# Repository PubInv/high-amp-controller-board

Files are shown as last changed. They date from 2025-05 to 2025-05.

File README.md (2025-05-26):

# high-amp-controller-board
A PCB assembly for controlling up to 60 amps of power for electolysis of electroplating

# Control V1.2 aka 1V1
Orginaly derived from NASA COG 1.1

On line schematic viewing from **Kicanvas** See: https://kicanvas.org  
The Control V1 is an Arduino DUE "Shield". The DUE will live below this printed wiring assembly. An Ethernet shield will live above as a "Socket". See KiCad Symbol & Footprint Library for Arduino Modules for "Shield" and "Socket"

## Schematics
### Browser page view of the schematic by KiCanvas.org 
Top page is "Control v1.kicad_sch". Note the page for MAX31856 is actualy for an MCP9600 but the page was not renamed (as of 20230830)
*  [Control1v1.kicad_sch](https://kicanvas.org/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)
* [Adafruit-MAX31850-thermocouple-breakout-board.kicad_sch](https://kicanvas.org/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)
* [Adafruit-MAX31855-breakout-board.kicad_sch](https://kicanvas.org/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)
* [Adafruit-MAX31856-PCB-master.kicad_sch](https://kicanvas.org/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)
* [Fan controller.kicad_sch](https://kicanvas.org/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)
* [I2C_Level_Shifter.kicad_sch](https://kicanvas.org/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)
* [SPI_ControllerLevel_Shifter.kicad_sch](https://kicanvas.org/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)
* [SSR Interface.kicad_sch](https://kicanvas.org/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)
* [display_interface.kicad_sch](https://kicanvas.org/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)

## PCB / PWA
### Browser page view of the PCB by KiCanvas.org 
Printed Circuit Board, Printed Wiring Assembly
* [Control 1v1.kicad_pcb](https://kicanvas.org/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)

### PCB / PWA 3D Snapshot


### BOM and Parts List
File Notes:
See notes on the Gerbers, BOM and placement files at:
https://github.com/PubInv/NASA-COG/issues/342

## License, Public Invention for this PCB, PWA
* [Firmware: Affero GPL 3.0](https://www.gnu.org/licenses/agpl-3.0.en.html#license-text)
* [CERN Open Hardware Licence Version 2 - Strongly Reciprocal](https://ohwr.org/cern_ohl_s_v2.txt)

<hr> 

## KiCad Symbol & Footprint Library for Arduino Modules
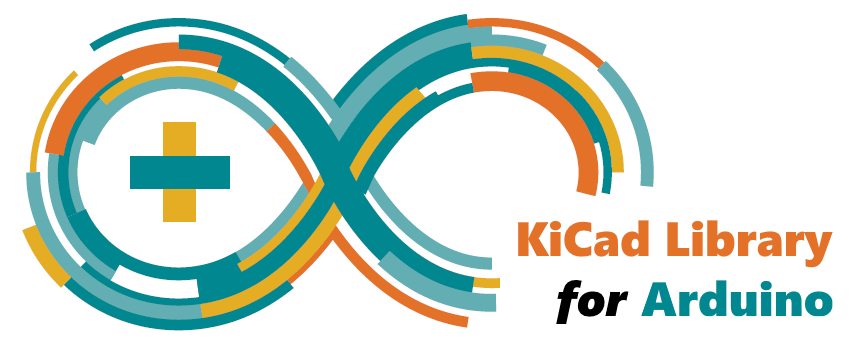
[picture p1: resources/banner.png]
<a href="./PICS/Rev2/PWA_FrontView.png">  
*Version 4.1.0*  

     

This is a library of KiCad schematic symbols and PCB footprints for most Arduino modules. You can use them to make your own PCB design which will effortlessly connect with your chosen Arduino module.

Currently included modules:
- Arduino **101** Shield
- Arduino **Due** Shield
- Arduino **Giga R1 WiFi** Shield
- Arduino **Leonardo** Shield
- Arduino **M0** Shield
- Arduino **M0 Pro** Shield
- Arduino **Mega 2560 R3** Shield
- Arduino **Micro** Socket
- Arduino **Mini** Socket
- Arduino **MKR 1000 WiFi** Socket
- Arduino **MKR WiFi 1010** Socket
- Arduino **MKR FOX 1200** Socket
- Arduino **MKR WAN 1300** Socket
- Arduino **MKR WAN 1310** Socket
- Arduino **MKR GSM 1400** Socket
- Arduino **MKR NB 1500** Socket
- Arduino **MKR Vidor 4000** Socket
- Arduino **MKR Zero** Socket
- Arduino **Nano** Socket
- Arduino **Nano 33 BLE** Socket / Tile
- Arduino **Nano 33 BLE Sense** Socket / Tile
- Arduino **Nano 33 BLE Sense R2** Socket / Tile
- Arduino **Nano 33 IoT** Socket / Tile
- Arduino **Nano Every** Socket / Tile
- Arduino **Nano RP2040 Connect** Socket / Tile
- Arduino **Nicla Sense ME** Socket / Tile
- Arduino **Nicla Vision** Socket / Tile
- Arduino **Nicla Voice** Socket / Tile
- Arduino **Pro Mini** Socket
- Arduino **Uno R1** Shield
- Arduino **Uno R2** Shield
- Arduino **Uno R3** Shield
- Arduino **Uno R3 SMD** Shield
- Arduino **Uno R4 Minima** Shield
- Arduino **Uno R4 WiFi** Shield
- Arduino **Uno WiFi R2** Shield
- Arduino **Zero** Shield
- Clone **Mega 2560 Pro** Socket
- Clone **Pro Mini** Socket

*"Shield" means the module is designed to plug in from beneath your PCB. "Socket" means the module is designed to plug in from above your PCB. "Tile" means the module is designed to be soldered directly on to your PCB using surface-mount pads.*

## KiCad Version Compatibility
This library requires at least KiCad 6 to function, and is tested on KiCad versions 6.0.8 and 7.0.2. Note that the installation procedure is different for KiCad 6 and 7; please see the [Library Installation](#library-installation) section below.

## Comments, Requests, Bugs & Contributions
All are welcome!
Please open an [Issue](https://github.com/Alarm-Siren/arduino-kicad-library/issues) or [Pull Request](https://github.com/Alarm-Siren/arduino-kicad-library/pulls), as appropriate.

## Library Installation
To install this library in your copy of KiCad, choose the correct section for your version of KiCad and follow the steps given. These instructions only cover automated installation using KiCad's built-in Package and Content Manager (PCM); manual installation is possible but not supported.

### KiCad 7

**Warning**: Do not change the nickname prefix from that given in step 4 below. If you do so KiCad will not assign the correct footprints to the symbols by default.

1. Open KiCad and open the Preferences window at "Preferences" -> "Preferences..."
2. Select the "Plugin and Content Manager" section in the left-hand pane.
3. Ensure that the "Automatically add installed libraries to the global lib table" option is ticked.
4. Ensure that the "Library nickname prefix" is set to "PCM_".
5. Ensuring that the "Check for package updates on startup" option is ticked is recommended. **(Optional)**
6. Click "OK" to close the Preferences window.
7. Click the "Plugin and Content Manager" button.
8. Select the "KiCad official repository" from the top drop-down box (if not already selected).
9. Go the Libraries tab and locate the "KiCad Library for Arduino Modules" in the list.
10. Click the "Install" button for that entry in the list.
11. Click "Apply Pending Changes".
12. Close the "Applying Package Changes" window once it has finished.
13. You should now find that this library is listed in the "Installed" tab.
14. Close the Plugin and Content Manager.
15. You may need to restart KiCad for the library installation to fully take effect. **(Optional)**
16. All done: you are now ready to use these schematic components and footprints in your projects!

### KiCad 6
**Recommendation:** If you can, you should upgrade to KiCad 7.

**Warning**: Do not change the Nicknames from those given in steps 12 and 18 below. If you do so KiCad will not assign the correct footprints to the symbols by default.

1. Open KiCad and click the "Plugin and Content Manager" button.
2. Select the "KiCad official repository" from the top drop-down box (if not already selected).
3. Go the Libraries tab and locate the "KiCad Library for Arduino Modules" in the list.
4. Click the "Install" button for that entry in the list.
5. Click "Apply Changes".
6. Close the "Applying Package Changes" window once it has finished.
7. You should now find that this library is listed in the "Installed" tab.
8. Close the Plugin and Content Manager.
9. Go to the "Preferences" -> "Manage Symbol Libraries..." menu option.
10. In the Symbol Libraries dialogue that appears, switch to the "Global Libraries" tab (if not already selected).
11. Click "Add empty row to table" button (the button with a big cross in it, beneath the table).
12. In the new line of the table, set the Nickname to "PCM_arduino-library", and ensure the Library Format is set to "KiCad".
13. In the same line of the table, set Library Path to "${KICAD6_3RD_PARTY}/symbols/com_github_alarm-siren_arduino-kicad-library/arduino-library.kicad_sym".
14. Click "OK" to close the Symbol Libraries dialogue.
15. Go to "Preferences" -> "Manage Footprint Libraries..." menu option.
16. In the Footprint Libraries dialogue that appears, switch to the "Global Libraries" tab (if not already selected).
17. Click "Add empty row to table" button (the button with a big cross in it, beneath the table).
18. In the new line of the table, set the Nickname to "PCM_arduino-library", and ensure the Library Format is set to "KiCad".
19. In the same line of the table, set Library Path to "${KICAD6_3RD_PARTY}/footprints/com_github_alarm-siren_arduino-kicad-library/arduino-library.pretty".
20. Click "OK" to close the Footprint Libraries dialogue.
21. All done: you are now ready to use these schematic components and footprints in your projects!

## Donations

I really hope you've found this library useful. If you'd like to buy me a beer in thanks for the work I put into it, you can make a donation using the button below:



## License & Legal
Copyright 2017-2023, [Nicholas Parks Young](https://github.com/Alarm-Siren).

Except as otherwise noted, all content of this library is licensed under the 
[Creative Commons Attribution-ShareAlike 4.0 International License](https://creativecommons.org/licenses/by-sa/4.0/), with the following additional exception:
> To the extent that the creation of electronic designs that use the Licensed Material can be considered to be Adapted Material, the Licensor waives Section 3 of the Public License with respect to these electronic designs and any generated files which incorporate data provided as part of the Licensed Material.



### "KiCad Library for Arduino" Banner & Icon

The two images "resources/banner.png" and "resources/icon.png" are licensed under the [Creative Commons Attribution-NonCommercial-ShareAlike 4.0 International License](https://creativecommons.org/licenses/by-nc-sa/4.0/). These images are derivatives of ["Arduino Open-Source Community: Main Logotype RGB Colors" originally created by Arduino](https://www.arduino.cc/en/trademark/community-logo). 

Original Images: Copyright 2013, [Arduino](https://www.arduino.cc/). Derived Images: Copyright 2023, [Nicholas Parks Young](https://github.com/Alarm-Siren).



### Arduino Trademark

The word "Arduino" is a registered trademark of [Arduino](https://www.arduino.cc/). This trademark is used in this library to refer to Arduino products and to identify Arduino-related non-commercial content, as permitted by Arduino's [trademark guidelines](https://www.arduino.cc/en/trademark). This project is not affiliated with nor endorsed by Arduino.

## FAQ

Answers to some common questions about this library.

### Is this library in active development?

Yes. For the foreseeable future, I will be providing support, bug-fixes and updating the library with any new Arduino modules as they are released.

### What does the license exception in the License & Legal section mean?

This library uses the same license as KiCad's own built-in parts library does, including the exception. The KiCad Libraries team have a [page which explains the meaning of the exception](https://www.kicad.org/libraries/license/). My version of the exception uses slightly better wording, but the effect is the same.

### Why do the footprints not have an `Edge.Cuts` outline?

If I put in an `Edge.Cuts` outline, then those users who want to have a PCB larger than the module footprint would have to modify the footprint to do so. In my experience, it is far more common for users to want a PCB larger than the module anyway, so I prefer to cater to those users. If you want your PCB to be the same size and shape as the Arduino module, you can trace the `F.Silkscreen` or `B.Silkscreen` layer (as appropriate) out in the `Edge.Cuts` layer yourself, or you can modify the footprint to change the outline from `F.Silkscreen` or `B.Silkscreen` layer to `Edge.Cuts`.

### Why do the Nicla Vision and Nicla Voice tile footprints have cut-outs?

The cut-outs are necessary to accommodate components on the back of those modules; without them the components would physically prevent you from getting the module's pads down to the footprint's SMD pads.

### Why does the whole footprint have an `F.Courtyard` or `B.Courtyard` outline? I can't place my components where I need to!

Firstly, this does not stop you from placing your components wherever you want. It does mean that the KiCad DRC will, by default, report errors or warnings in some circumstances because the module footprint and your circuit's footprints' courtyards are overlapping, but you can ignore or disable these errors/warnings without issue.

Secondly, the intention is that it acts as a warning to the user that they've put components in the 'danger zone' between their PCB and the Module. I do not model all of the tall components on the module, so it is possible that a user might unknowingly place their own tall component in a position that would conflict with one on the module. My hope is that the DRC errors/warnings will flag this potential problem to the user to manually check that their placement does not conflict with the module.

In principle I'm open to marking the taller components specifically, which would remove this issue, but this is a lot of work and requires data I don't have access to for all the modules.

### Why is this Power Pin set to Power Input/Power Output/Unconnected? I get DRC errors because of it!

The short answer is that some power pins on some modules can be used as either inputs or outputs, depending on your circuit design / where you're powering the assembly from.

For those pins where I've been able to categorically confirm that the given power pin is Unconnected by default, or must necessarily be a Power Input or a Power Output, I have set it as such. For those pins that can be used as either an input or output, I have set it to Power Input as this is the more flexible option whilst still preserving some element of DRC capability. If you're using one of these Power Input pins as a Power Output from the module, you'll need to add the special "PWR_FLAG" component to the affected net to make the DRC error go away.

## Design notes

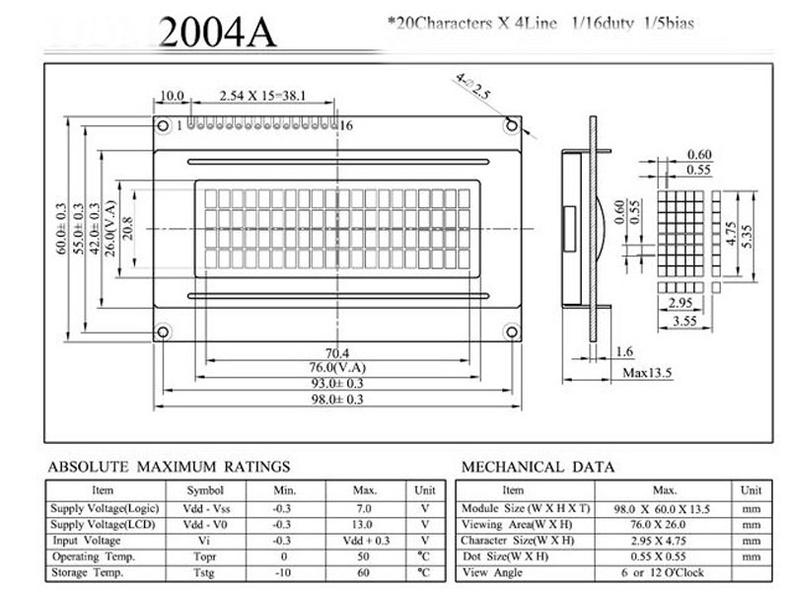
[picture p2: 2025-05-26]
PublicInvention_KiCad_Library/Parts/20x4DisplayMechanical.jpg

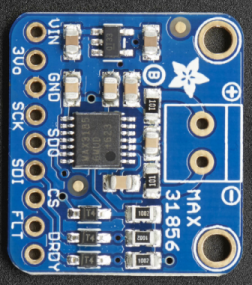
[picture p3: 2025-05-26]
resources/Adafruit_MAX31856.png

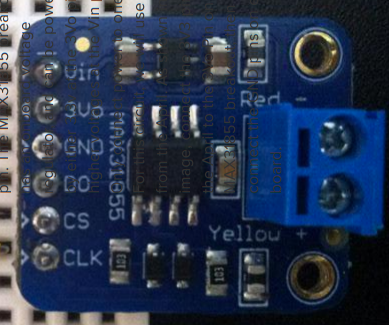
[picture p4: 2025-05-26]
resources/Adafruit_MAX31855.png

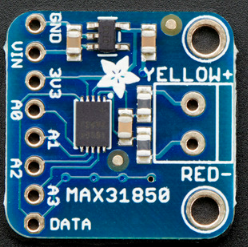
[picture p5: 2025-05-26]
resources/Adafruit_MAX31850.png

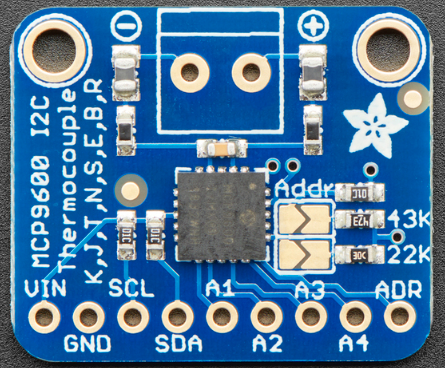
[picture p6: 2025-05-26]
resources/Adafruit_MCP9600.png

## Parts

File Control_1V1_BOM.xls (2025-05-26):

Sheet: RAW
Source: | C:\Users\Public\Downloads\Arduino\PubInv\NASA-COG\elec\Control Board\Control_1v1\Control_1v1\Control_1v1.kicad_sch
Date: | 10/11/2023 9:02:01 PM
Tool: | Eeschema 7.0.5
Generator: | C:\Program Files\KiCad\6.0\bin\scripting\plugins/bom_csv_grouped_by_value.py
Component Count: | 287
Individual Components:
Item | Qty | Reference(s) | Value | LibPart | Footprint | Datasheet | Assembly Type | AssemblyType | Category | Cost | DK_Datasheet_Link | DK_Detail_Page | Description | Digi-Key_PN | Distributor 1 | Distributor 1 PN | Distributor 2 | Distributor 2 PN | Family | LongLead | MPN | Manufacturer | Part Number | Status
 |  | A1 | Arduino_Due_Shield | arduino-library:Arduino_Due_Shield | PubInv_KiCad_PCB:Arduino_Due_Shield_Annotated | https://docs.arduino.cc/hardware/due
 |  | C1 | 39pF | Device:C | Capacitor_SMD:C_0603_1608Metric_Pad1.08x0.95mm_HandSolder | https://datasheet.lcsc.com/lcsc/1811082118_YAGEO-CC0603JRNPO9BN390_C107049.pdf |  | SMT |  | 0.003 |  |  | 50V 39pF NP0 Â±5% 0603 Multilayer Ceramic Ca |  | JLCPCB | C107049 |  |  |  | NO | CC0603JRNPO9BN390 | YAGEO
 |  | C2 | 39pF | Device:C | Capacitor_SMD:C_0603_1608Metric_Pad1.08x0.95mm_HandSolder | https://datasheet.lcsc.com/lcsc/1811082118_YAGEO-CC0603JRNPO9BN390_C107049.pdf |  | SMT |  | 0.003 |  |  | 50V 39pF NP0 Â±5% 0603 Multilayer Ceramic Ca |  | JLCPCB | C107049 |  |  |  | NO | CC0603JRNPO9BN390 | YAGEO
 |  | C3 | 39pF | Device:C | Capacitor_SMD:C_0603_1608Metric_Pad1.08x0.95mm_HandSolder | https://datasheet.lcsc.com/lcsc/1811082118_YAGEO-CC0603JRNPO9BN390_C107049.pdf |  | SMT |  | 0.003 |  |  | 50V 39pF NP0 Â±5% 0603 Multilayer Ceramic Ca |  | JLCPCB | C107049 |  |  |  | NO | CC0603JRNPO9BN390 | YAGEO
 |  | C4 | 39pF | Device:C | Capacitor_SMD:C_0603_1608Metric_Pad1.08x0.95mm_HandSolder | https://datasheet.lcsc.com/lcsc/1811082118_YAGEO-CC0603JRNPO9BN390_C107049.pdf |  | SMT |  | 0.003 |  |  | 50V 39pF NP0 Â±5% 0603 Multilayer Ceramic Ca |  | JLCPCB | C107049 |  |  |  | NO | CC0603JRNPO9BN390 | YAGEO
 |  | C5 | 39pF | Device:C | Capacitor_SMD:C_0603_1608Metric_Pad1.08x0.95mm_HandSolder | https://datasheet.lcsc.com/lcsc/1811082118_YAGEO-CC0603JRNPO9BN390_C107049.pdf |  | SMT |  | 0.003 |  |  | 50V 39pF NP0 Â±5% 0603 Multilayer Ceramic Ca |  | JLCPCB | C107049 |  |  |  | NO | CC0603JRNPO9BN390 | YAGEO
 |  | C6 | 39pF | Device:C | Capacitor_SMD:C_0603_1608Metric_Pad1.08x0.95mm_HandSolder | https://datasheet.lcsc.com/lcsc/1811082118_YAGEO-CC0603JRNPO9BN390_C107049.pdf |  | SMT |  | 0.003 |  |  | 50V 39pF NP0 Â±5% 0603 Multilayer Ceramic Ca |  | JLCPCB | C107049 |  |  |  | NO | CC0603JRNPO9BN390 | YAGEO
 |  | C7 | 39pF | Device:C | Capacitor_SMD:C_0603_1608Metric_Pad1.08x0.95mm_HandSolder | https://datasheet.lcsc.com/lcsc/1811082118_YAGEO-CC0603JRNPO9BN390_C107049.pdf |  | SMT |  | 0.003 |  |  | 50V 39pF NP0 Â±5% 0603 Multilayer Ceramic Ca |  | JLCPCB | C107049 |  |  |  | NO | CC0603JRNPO9BN390 | YAGEO
 |  | C8 | 39pF | Device:C | Capacitor_SMD:C_0603_1608Metric_Pad1.08x0.95mm_HandSolder | https://datasheet.lcsc.com/lcsc/1811082118_YAGEO-CC0603JRNPO9BN390_C107049.pdf |  | SMT |  | 0.003 |  |  | 50V 39pF NP0 Â±5% 0603 Multilayer Ceramic Ca |  | JLCPCB | C107049 |  |  |  | NO | CC0603JRNPO9BN390 | YAGEO
 |  | C9 | 39pF | Device:C | Capacitor_SMD:C_0603_1608Metric_Pad1.08x0.95mm_HandSolder | https://datasheet.lcsc.com/lcsc/1811082118_YAGEO-CC0603JRNPO9BN390_C107049.pdf |  | SMT |  | 0.003 |  |  | 50V 39pF NP0 Â±5% 0603 Multilayer Ceramic Ca |  | JLCPCB | C107049 |  |  |  | NO | CC0603JRNPO9BN390 | YAGEO
 |  | C10 | 39pF | Device:C | Capacitor_SMD:C_0603_1608Metric_Pad1.08x0.95mm_HandSolder | https://datasheet.lcsc.com/lcsc/1811082118_YAGEO-CC0603JRNPO9BN390_C107049.pdf |  | SMT |  | 0.003 |  |  | 50V 39pF NP0 Â±5% 0603 Multilayer Ceramic Ca |  | JLCPCB | C107049 |  |  |  | NO | CC0603JRNPO9BN390 | YAGEO
 |  | C11 | 39pF | Device:C | Capacitor_SMD:C_0603_1608Metric_Pad1.08x0.95mm_HandSolder | https://datasheet.lcsc.com/lcsc/1811082118_YAGEO-CC0603JRNPO9BN390_C107049.pdf |  | SMT |  | 0.003 |  |  | 50V 39pF NP0 Â±5% 0603 Multilayer Ceramic Ca |  | JLCPCB | C107049 |  |  |  | NO | CC0603JRNPO9BN390 | YAGEO
 |  | C12 | 39pF | Device:C | Capacitor_SMD:C_0603_1608Metric_Pad1.08x0.95mm_HandSolder | https://datasheet.lcsc.com/lcsc/1811082118_YAGEO-CC0603JRNPO9BN390_C107049.pdf |  | SMT |  | 0.003 |  |  | 50V 39pF NP0 Â±5% 0603 Multilayer Ceramic Ca |  | JLCPCB | C107049 |  |  |  | NO | CC0603JRNPO9BN390 | YAGEO
 |  | C13 | 39pF | Device:C | Capacitor_SMD:C_0603_1608Metric_Pad1.08x0.95mm_HandSolder | https://datasheet.lcsc.com/lcsc/1811082118_YAGEO-CC0603JRNPO9BN390_C107049.pdf |  | SMT |  | 0.003 |  |  | 50V 39pF NP0 Â±5% 0603 Multilayer Ceramic Ca |  | JLCPCB | C107049 |  |  |  | NO | CC0603JRNPO9BN390 | YAGEO
 |  | C14 | 39pF | Device:C | Capacitor_SMD:C_0603_1608Metric_Pad1.08x0.95mm_HandSolder | https://datasheet.lcsc.com/lcsc/1811082118_YAGEO-CC0603JRNPO9BN390_C107049.pdf |  | SMT |  | 0.003 |  |  | 50V 39pF NP0 Â±5% 0603 Multilayer Ceramic Ca |  | JLCPCB | C107049 |  |  |  | NO | CC0603JRNPO9BN390 | YAGEO
 |  | C15 | 39pF | Device:C | Capacitor_SMD:C_0603_1608Metric_Pad1.08x0.95mm_HandSolder | https://datasheet.lcsc.com/lcsc/1811082118_YAGEO-CC0603JRNPO9BN390_C107049.pdf |  | SMT |  | 0.003 |  |  | 50V 39pF NP0 Â±5% 0603 Multilayer Ceramic Ca |  | JLCPCB | C107049 |  |  |  | NO | CC0603JRNPO9BN390 | YAGEO
 |  | C16 | 1uF | Device:C | Capacitor_SMD:C_0603_1608Metric_Pad1.08x0.95mm_HandSolder | CC0603JRX7R9BB104.pdf |  | SMT |  | 0.0037 |  |  | 50V 1uF Â±5% 0603 Multilayer Ceramic Ca |  | JLCPCB | C91183 |  |  |  | NO | CC0603JRX7R9BB104 | YAGEO
 |  | C17 | 1uF | Device:C | Capacitor_SMD:C_0603_1608Metric_Pad1.08x0.95mm_HandSolder | CC0603JRX7R9BB104.pdf |  | SMT |  | 0.0037 |  |  | 50V 1uF Â±5% 0603 Multilayer Ceramic Ca |  | JLCPCB | C91183 |  |  |  | NO | CC0603JRX7R9BB104 | YAGEO
 |  | C18 | 1uF | Device:C | Capacitor_SMD:C_0603_1608Metric_Pad1.08x0.95mm_HandSolder | CC0603JRX7R9BB104.pdf |  | SMT |  | 0.0037 |  |  | 50V 1uF Â±5% 0603 Multilayer Ceramic Ca |  | JLCPCB | C91183 |  |  |  | NO | CC0603JRX7R9BB104 | YAGEO
 |  | C19 | 1uF | Device:C | Capacitor_SMD:C_0603_1608Metric_Pad1.08x0.95mm_HandSolder | CC0603JRX7R9BB104.pdf |  | SMT |  | 0.0037 |  |  | 50V 1uF Â±5% 0603 Multilayer Ceramic Ca |  | JLCPCB | C91183 |  |  |  | NO | CC0603JRX7R9BB104 | YAGEO
 |  | C20 | 39pF | Device:C | Capacitor_SMD:C_0603_1608Metric_Pad1.08x0.95mm_HandSolder | https://datasheet.lcsc.com/lcsc/1811082118_YAGEO-CC0603JRNPO9BN390_C107049.pdf |  | SMT |  | 0.003 |  |  | 50V 39pF NP0 Â±5% 0603 Multilayer Ceramic Ca |  | JLCPCB | C107049 |  |  |  | NO | CC0603JRNPO9BN390 | YAGEO
 |  | C21 | 39pF | Device:C | Capacitor_SMD:C_0603_1608Metric_Pad1.08x0.95mm_HandSolder | https://datasheet.lcsc.com/lcsc/1811082118_YAGEO-CC0603JRNPO9BN390_C107049.pdf |  | SMT |  | 0.003 |  |  | 50V 39pF NP0 Â±5% 0603 Multilayer Ceramic Ca |  | JLCPCB | C107049 |  |  |  | NO | CC0603JRNPO9BN390 | YAGEO
 |  | C22 | 10nF | Device:C | Capacitor_SMD:C_0603_1608Metric_Pad1.08x0.95mm_HandSolder | ~ |  | SMT |  | 0.0132 |  |  |  |  | JLCPCB | C389113 |  |  |  |  | CC0603JRNPO9BN103 | YAGEO
 |  | C23 | 39pF | Device:C | Capacitor_SMD:C_0603_1608Metric_Pad1.08x0.95mm_HandSolder | https://datasheet.lcsc.com/lcsc/1811082118_YAGEO-CC0603JRNPO9BN390_C107049.pdf |  | SMT |  | 0.003 |  |  | 50V 39pF NP0 Â±5% 0603 Multilayer Ceramic Ca |  | JLCPCB | C107049 |  |  |  | NO | CC0603JRNPO9BN390 | YAGEO
 |  | CIPO1 | CIPO | Connector:TestPoint | TestPoint:TestPoint_Loop_D2.54mm_Drill1.5mm_Beaded | ~ |  | HAND |  | 0
 |  | COPI1 | COPI | Connector:TestPoint | TestPoint:TestPoint_Loop_D2.54mm_Drill1.5mm_Beaded | ~ |  | HAND |  | 0
 |  | D1 | 5.1V | Diode:BZV55B3V3 | Diode_SMD:D_MiniMELF | https://assets.nexperia.com/documents/data-sheet/BZV55_SER.pdf BZV55B3V3 |  | SMT |  | 0.0433 |  |  | Â±5% Single 1W 5.1V MELF Zener Diodes ROHS |  | JLCPCB | C841097 |  |  |  |  | DL4733A | LGE
 |  | D2 | 5.1V | Diode:BZV55B3V3 | Diode_SMD:D_MiniMELF | https://assets.nexperia.com/documents/data-sheet/BZV55_SER.pdf BZV55B3V3 |  | SMT |  | 0.0433 |  |  | Â±5% Single 1W 5.1V MELF Zener Diodes ROHS |  | JLCPCB | C841097 |  |  |  |  | DL4733A | LGE
 |  | D3 | 1N5819WS | Diode:1N5819WS | Diode_SMD:D_SOD-323 | https://datasheet.lcsc.com/lcsc/2204281430_Guangdong-Hottech-1N5819WS_C191023.pdf |  | SMT |  | 0.0119 |  |  | 40V 600mV@1A 1A SOD-323 Schottky Barrier Diodes (SBD) ROHS |  | JLCPCB | C191023 |  |  |  |  | 1N5819WS | Guangdong Hottech
 |  | D4 | RED 0603 | Device:LED | LED_SMD:LED_0603_1608Metric_Pad1.05x0.95mm_HandSolder | ~ |  | HAND | Optoelectronics | 0.0054 | http://optoelectronics.liteon.com/upload/download/DS22-2000-109/LTST-C171KRKT.pdf | /product-detail/en/lite-on-inc/LTST-C171KRKT/160-1427-1-ND/386800 | LED RED CLEAR SMD | 160-1427-1-ND | JLCPCB | C2286 |  |  | LED Indication - Discrete |  | LTST-C171KRKT | Lite-On Inc. |  | Active
 |  | D_PSU_RX1 | D_PSU_RX | Connector:TestPoint | TestPoint:TestPoint_Loop_D2.54mm_Drill1.5mm_Beaded | ~ |  | HAND |  | 0
 |  | D_PSU_RX2 | D_PSU_RX2 | Connector:TestPoint | TestPoint:TestPoint_Loop_D2.54mm_Drill1.5mm_Beaded | ~ |  | HAND |  | 0
 |  | D_PSU_TX1 | D_PSU_TX | Connector:TestPoint | TestPoint:TestPoint_Loop_D2.54mm_Drill1.5mm_Beaded | ~ |  | HAND |  | 0
 |  | D_PSU_TX2 | D_PSU_TX2 | Connector:TestPoint | TestPoint:TestPoint_Loop_D2.54mm_Drill1.5mm_Beaded | ~ |  | HAND |  | 0
 |  | H1 | MountingHole_Pad_3.5mm | GPAD_SCH_LIB:MountingHole_Pad_3.5mm | PubInv_KiCad_PCB:MountingHole_3.5mm_Pad_Via | ~ |  | NA |  | 0 |  |  | MountingHole_Pad_3.5mm |  | NA | NA
 |  | H2 | MountingHole_Pad_3.5mm | GPAD_SCH_LIB:MountingHole_Pad_3.5mm | PubInv_KiCad_PCB:MountingHole_3.5mm_Pad_Via | ~ |  | NA |  | 0 |  |  | MountingHole_Pad_3.5mm |  | NA | NA
 |  | H3 | MountingHole_Pad_3.5mm | GPAD_SCH_LIB:MountingHole_Pad_3.5mm | PubInv_KiCad_PCB:MountingHole_3.5mm_Pad_Via | ~ |  | NA |  | 0 |  |  | MountingHole_Pad_3.5mm |  | NA | NA
 |  | H4 | MountingHole_Pad_3.5mm | GPAD_SCH_LIB:MountingHole_Pad_3.5mm | PubInv_KiCad_PCB:MountingHole_3.5mm_Pad_Via | ~ |  | NA |  | 0 |  |  | MountingHole_Pad_3.5mm |  | NA | NA
 |  | H5 | MountingHole_Pad_3.5mm | GPAD_SCH_LIB:MountingHole_Pad_3.5mm | PubInv_KiCad_PCB:MountingHole_3.5mm_Pad_Via | ~ |  | NA |  | 0 |  |  | MountingHole_Pad_3.5mm |  | NA | NA
 |  | ISO1 | MountingHole_Pad_3.5mm | GPAD_SCH_LIB:MountingHole_Pad_3.5mm | PubInv_KiCad_PCB:MountingHole_3.5mm_Pad_Via | ~ |  | NA |  | 0 |  |  | MountingHole_Pad_3.5mm |  | NA | NA
 |  | ISO2 | MountingHole_Pad_3.5mm | GPAD_SCH_LIB:MountingHole_Pad_3.5mm | PubInv_KiCad_PCB:MountingHole_3.5mm_Pad_Via | ~ |  | NA |  | 0 |  |  | MountingHole_Pad_3.5mm |  | NA | NA
 |  | ISO3 | MountingHole_Pad_3.5mm | GPAD_SCH_LIB:MountingHole_Pad_3.5mm | PubInv_KiCad_PCB:MountingHole_3.5mm_Pad_Via | ~ |  | NA |  | 0 |  |  | MountingHole_Pad_3.5mm |  | NA | NA
 |  | ISO4 | MountingHole_Pad_3.5mm | GPAD_SCH_LIB:MountingHole_Pad_3.5mm | PubInv_KiCad_PCB:MountingHole_3.5mm_Pad_Via | ~ |  | NA |  | 0 |  |  | MountingHole_Pad_3.5mm |  | NA | NA
 |  | ISO5 | MountingHole_Pad_3.5mm | GPAD_SCH_LIB:MountingHole_Pad_3.5mm | PubInv_KiCad_PCB:MountingHole_3.5mm_Pad_Via | ~ |  | NA |  | 0 |  |  | MountingHole_Pad_3.5mm |  | NA | NA
 |  | J1 | DB9_Female_MountingHoles | Connector:DB9_Female_MountingHoles | Connector_Dsub:DSUB-9_Female_Horizontal_P2.77x2.84mm_EdgePinOffset4.94mm_Housed_MountingHolesOffset7.48mm | C141882_D-DMR009PF-D002.pdf |  | HAND |  | 0.2718 |  |  | 9P Female D-Sub Shrouded 2 3A -50â„ƒ~+105â„ƒ Plugin D-Sub/DVI/HDMI Connectors ROHS |  | JLCPCB | C141882 |  |  |  |  | D-DMR009PF-D002 | Ckmtw(Shenzhen Cankemeng)
 |  | J2 | Conn_01x08 | Connector_Generic:Conn_01x08 | Connector_PinSocket_2.54mm:PinSocket_1x08_P2.54mm_Vertical | https://jlcpcb.com/partdetail/Hctl-PZ254_1_08_Z_85/C2894931 |  | HAND |  | 0.0762 |  |  | 3A Straight Square Pins 2.5mm 8P 6mm -40â„ƒ~+105â„ƒ 3mm 2.54mm Plugin Black 1x8P Plugin,P=2.54mm Pin Headers ROHS |  | JLCPCB | C2894931 |  |  |  |  | PZ254-1-08-Z-8.5 | HCTL
 |  | J3 | Conn_01x08 | Connector_Generic:Conn_01x08 | Connector_PinSocket_2.54mm:PinSocket_1x08_P2.54mm_Vertical | https://jlcpcb.com/partdetail/Hctl-PZ254_1_08_Z_85/C2894931 |  | HAND |  | 0.0762 |  |  | 3A Straight Square Pins 2.5mm 8P 6mm -40â„ƒ~+105â„ƒ 3mm 2.54mm Plugin Black 1x8P Plugin,P=2.54mm Pin Headers ROHS |  | JLCPCB | C2894931 |  |  |  |  | PZ254-1-08-Z-8.5 | HCTL
 |  | J4 | Conn_01x08 | Connector_Generic:Conn_01x08 | Connector_PinSocket_2.54mm:PinSocket_1x08_P2.54mm_Vertical | https://jlcpcb.com/partdetail/Hctl-PZ254_1_08_Z_85/C2894931 |  | HAND |  | 0.0762 |  |  | 3A Straight Square Pins 2.5mm 8P 6mm -40â„ƒ~+105â„ƒ 3mm 2.54mm Plugin Black 1x8P Plugin,P=2.54mm Pin Headers ROHS |  | JLCPCB | C2894931 |  |  |  |  | PZ254-1-08-Z-8.5 | HCTL
 |  | J5 | Conn_01x08 | Connector_Generic:Conn_01x08 | Connector_PinSocket_2.54mm:PinSocket_1x08_P2.54mm_Vertical | https://jlcpcb.com/partdetail/Hctl-PZ254_1_08_Z_85/C2894931 |  | HAND |  | 0.0762 |  |  | 3A Straight Square Pins 2.5mm 8P 6mm -40â„ƒ~+105â„ƒ 3mm 2.54mm Plugin Black 1x8P Plugin,P=2.54mm Pin Headers ROHS |  | JLCPCB | C2894931 |  |  |  |  | PZ254-1-08-Z-8.5 | HCTL
 |  | J6 | Conn_01x08 | Connector_Generic:Conn_01x08 | Connector_PinSocket_2.54mm:PinSocket_1x08_P2.54mm_Vertical | https://jlcpcb.com/partdetail/Hctl-PZ254_1_08_Z_85/C2894931 |  | HAND |  | 0.0762 |  |  | 3A Straight Square Pins 2.5mm 8P 6mm -40â„ƒ~+105â„ƒ 3mm 2.54mm Plugin Black 1x8P Plugin,P=2.54mm Pin Headers ROHS |  | JLCPCB | C2894931 |  |  |  |  | PZ254-1-08-Z-8.5 | HCTL
 |  | J7 | Conn_01x10 | Connector_Generic:Conn_01x10 | Connector_PinSocket_2.54mm:PinSocket_1x10_P2.54mm_Vertical | https://jlcpcb.com/partdetail/Hctl-PZ254_1_10_Z_85/C2894933 |  | HAND |  | 0.0942 |  |  | 3A Straight Square Pins 2.5mm 10P 6mm -40â„ƒ~+105â„ƒ 3mm 2.54mm Plugin Black 1x10P Plugin,P=2.54mm Pin Headers ROHS |  | JLCPCB | C2894933 |  |  |  |  | PZ254-1-10-Z-8.5 | HCTL
 |  | J8 | Conn_02x18_Odd_Even | Connector_Generic:Conn_02x18_Odd_Even | Connector_PinSocket_2.54mm:PinSocket_2x18_P2.54mm_Vertical | C132131_DS1023-2_18SF11.pdf |  | HAND |  | 0.3441 |  |  | 2.54mm 2.54mm åŒæŽ’ 36P Straight 2x18P Plugin,P=2.54mm Female Headers ROHS |  | JLCPCB | C132131
 |  | J9 | Conn_01x10 | Connector_Generic:Conn_01x10 | Connector_PinSocket_2.54mm:PinSocket_1x10_P2.54mm_Vertical | https://jlcpcb.com/partdetail/Hctl-PZ254_1_10_Z_85/C2894933 |  | HAND |  | 0.0942 |  |  | 3A Straight Square Pins 2.5mm 10P 6mm -40â„ƒ~+105â„ƒ 3mm 2.54mm Plugin Black 1x10P Plugin,P=2.54mm Pin Headers ROHS |  | JLCPCB | C2894933 |  |  |  |  | PZ254-1-10-Z-8.5 | HCTL
 |  | J10 | Conn_02x12_Odd_Even | Connector_Generic:Conn_02x12_Odd_Even | PubInv_KiCad_PCB.pretty:PinHeader_2x12_P2.00mm_Vertical_JST | https://www.jst-mfg.com/product/pdf/eng/ePHD.pdf |  | HAND |  | 1000000 |  |  |  |  |  |  | JLCPCB | ?https://jlcpcb.com/partdetail/Jst_SalesAmerica-B24B_PHDSS_B_LF_SN/C160327? |  |  |  |  | B24B-PHDSS
 |  | J11 | Screw_Terminal_01x02 | Connector:Screw_Terminal_01x02 | TerminalBlock_TE-Connectivity:TerminalBlock_TE_282834-2_1x02_P2.54mm_Horizontal | DB128V-5.08-2P-GN-S.pdf |  | HAND |  | 0.1537 |  |  | 1x2P 20A -40â„ƒ~+105â„ƒ 300V Green 12~30 Straight pin 5.08mm 2.5 1 2 Plugin,P=5.08mm Screw terminal ROHS |  | JLCPCB | C918120 |  |  |  |  | DB125-2.54-2P-GN-S | DIBO
 |  | J12 | Screw_Terminal_01x02 | Connector:Screw_Terminal_01x02 | TerminalBlock_TE-Connectivity:TerminalBlock_TE_282834-2_1x02_P2.54mm_Horizontal | DB128V-5.08-2P-GN-S.pdf |  | HAND |  | 0.1537 |  |  | 1x2P 20A -40â„ƒ~+105â„ƒ 300V Green 12~30 Straight pin 5.08mm 2.5 1 2 Plugin,P=5.08mm Screw terminal ROHS |  | JLCPCB | C918120 |  |  |  |  | DB125-2.54-2P-GN-S | DIBO
 |  | J13 | Screw_Terminal_01x02 | Connector:Screw_Terminal_01x02 | TerminalBlock_TE-Connectivity:TerminalBlock_TE_282834-2_1x02_P2.54mm_Horizontal | DB128V-5.08-2P-GN-S.pdf |  | HAND |  | 0.1537 |  |  | 1x2P 20A -40â„ƒ~+105â„ƒ 300V Green 12~30 Straight pin 5.08mm 2.5 1 2 Plugin,P=5.08mm Screw terminal ROHS |  | JLCPCB | C918120 |  |  |  |  | DB125-2.54-2P-GN-S | DIBO
 |  | J14 | Conn_01x10 | Connector_Generic:Conn_01x10 | Connector_PinSocket_2.54mm:PinSocket_1x10_P2.54mm_Vertical | https://jlcpcb.com/partdetail/Hctl-PZ254_1_10_Z_85/C2894933 |  | HAND |  | 0.0942 |  |  | 3A Straight Square Pins 2.5mm 10P 6mm -40â„ƒ~+105â„ƒ 3mm 2.54mm Plugin Black 1x10P Plugin,P=2.54mm Pin Headers ROHS |  | JLCPCB | C2894933 |  |  |  |  | PZ254-1-10-Z-8.5 | HCTL
 |  | J15 | DB25_Female_MountingHoles | Connector:DB25_Female_MountingHoles | Connector_Dsub:DSUB-25_Female_Horizontal_P2.77x2.84mm_EdgePinOffset4.94mm_Housed_MountingHolesOffset7.48mm | C190083_D-DMR025PF-D002.pdf |  | HAND |  | 0.7217 |  |  | 25P Female D-Sub Shrouded 2 3A -50â„ƒ~+105â„ƒ Plugin D-Sub/DVI/HDMI Connectors ROHS |  | JLCPCB | C190083 |  |  |  |  | D-DMR025PF-D002 | Ckmtw(Shenzhen Cankemeng)
 |  | J16 | Conn_01x04 | Connector_Generic:Conn_01x04 | Connector_PinHeader_2.54mm:PinHeader_1x04_P2.54mm_Vertical | KH-2.54FH-1X4P-H8.5.pdf |  | HAND |  | 0.0342 |  |  | 2.54mm Plugin 3A 4P -40â„ƒ~+105â„ƒ Straight 1x4P 8.5mm Top Square Holes Plugin,P=2.54mm Female Headers ROHS |  | JLCPCB | C2905415 |  |  |  |  | KH-2.54FH-1X4P-H8.5 | Shenzhen Kinghelm Elec
 |  | J17 | Conn_01x05 | Connector_Generic:Conn_01x05 | Connector_PinHeader_2.54mm:PinHeader_1x05_P2.54mm_Vertical | C2897368_PM254-1-05-Z-8.5.pdf |  | HAND |  | 0.0791 |  |  | 2.54mm Plugin 3A 5P -40â„ƒ~+105â„ƒ Straight 1x5P 8.5mm Top Square Holes Plugin,P=2.54mm Female Headers ROHS |  | JLCPCB | C2897368 |  |  |  |  | PM254-1-05-Z-8.5 | HCTL
 |  | J18 | Conn_01x04 | Connector_Generic:Conn_01x04 | Connector_PinHeader_2.54mm:PinHeader_1x04_P2.54mm_Vertical | KH-2.54FH-1X4P-H8.5.pdf |  | HAND |  | 0.0342 |  |  | 2.54mm Plugin 3A 4P -40â„ƒ~+105â„ƒ Straight 1x4P 8.5mm Top Square Holes Plugin,P=2.54mm Female Headers ROHS |  | JLCPCB | C2905415 |  |  |  |  | KH-2.54FH-1X4P-H8.5 | Shenzhen Kinghelm Elec
 |  | J19 | Conn_01x07 | Connector_Generic:Conn_01x07 | Connector_PinHeader_2.54mm:PinHeader_1x07_P2.54mm_Vertical | C2932672_KH-2.54FH-1X7P-H8.5.pdf |  | HAND |  | 0.0543 |  |  | 2.54mm Plugin 3A 7P -40â„ƒ~+105â„ƒ Straight 1x7P 8.5mm Top Square Holes Plugin,P=2.54mm Female Headers ROHS |  | JLCPCB | C2932672
 |  | J20 | Conn_01x04 | Connector:Conn_01x04_Pin | Connector_PinHeader_2.54mm:PinHeader_1x04_P2.54mm_Vertical | KH-2.54FH-1X4P-H8.5.pdf |  | HAND |  | 0.0342 |  |  | 2.54mm Plugin 3A 4P -40â„ƒ~+105â„ƒ Straight 1x4P 8.5mm Top Square Holes Plugin,P=2.54mm Female Headers ROHS |  | JLCPCB | C2905415 |  |  |  |  | KH-2.54FH-1X4P-H8.5 | Shenzhen Kinghelm Elec
 |  | J21 | RJ12_6P6C_HORZ | GPAD_SCH_LIB:RJ12_6P6C_HORZ | PubInv_KiCad_PCB:RJ12_Amphenol_54601 | https://datasheet.lcsc.com/lcsc/1811141146_TE-Connectivity-5555165-1_C305981.pdf |  | HAND |  | 0.8901 |  |  | Jack Modular Connector 6p6c (RJ11, RJ12, RJ14, RJ25) 90Â° Angle (Right) Unshielded Cat3 |  | JLCPCB | C305981 | Digikey | A31422-ND |  | YES | 5555165-1 | TE Connectivity
 |  | J22 | 0.100_2Pin | GPAD_SCH_LIB:22-23-2021 | Connector_PinHeader_2.54mm:PinHeader_1x02_P2.54mm_Vertical | https://datasheet.lcsc.com/lcsc/1811011511_Amphenol-ICC-68000-102HLF_C168673.pdf | HAND | HAND | Connectors, Interconnects | 0.1458 | https://media.digikey.com/pdf/Data%20Sheets/Molex%20PDFs/A-6373-N_Series_Dwg_2010-12-03.pdf | /product-detail/en/molex/22-23-2021/WM4200-ND/26667 | HEADER VERT 2POS 2.54MM | WM4200-ND | JLCPCB | C168673 |  |  | Rectangular Connectors - Headers, Male Pins | YES | 68000-102HLF | Amphenol ICC |  | Active
 |  | J23 | 0.100_2Pin | GPAD_SCH_LIB:22-23-2021 | Connector_PinHeader_2.54mm:PinHeader_1x02_P2.54mm_Vertical | https://datasheet.lcsc.com/lcsc/1811011511_Amphenol-ICC-68000-102HLF_C168673.pdf | HAND | HAND | Connectors, Interconnects | 0.1458 | https://media.digikey.com/pdf/Data%20Sheets/Molex%20PDFs/A-6373-N_Series_Dwg_2010-12-03.pdf | /product-detail/en/molex/22-23-2021/WM4200-ND/26667 | HEADER VERT 2POS 2.54MM | WM4200-ND | JLCPCB | C168673 |  |  | Rectangular Connectors - Headers, Male Pins | YES | 68000-102HLF | Amphenol ICC |  | Active
 |  | J24 | Conn_01x04 | Connector_Generic:Conn_01x04 | Connector_PinHeader_2.54mm:PinHeader_1x04_P2.54mm_Vertical | KH-2.54FH-1X4P-H8.5.pdf |  | HAND |  | 0.0342 |  |  | 2.54mm Plugin 3A 4P -40â„ƒ~+105â„ƒ Straight 1x4P 8.5mm Top Square Holes Plugin,P=2.54mm Female Headers ROHS |  | JLCPCB | C2905415 |  |  |  |  | KH-2.54FH-1X4P-H8.5 | Shenzhen Kinghelm Elec
 |  | J25 | Screw_Terminal_01x02 | Connector:Screw_Terminal_01x02 | TerminalBlock_TE-Connectivity:TerminalBlock_TE_282834-2_1x02_P2.54mm_Horizontal | DB128V-5.08-2P-GN-S.pdf |  | HAND |  | 0.1537 |  |  | 1x2P 20A -40â„ƒ~+105â„ƒ 300V Green 12~30 Straight pin 5.08mm 2.5 1 2 Plugin,P=5.08mm Screw terminal ROHS |  | JLCPCB | C918120 |  |  |  |  | DB125-2.54-2P-GN-S | DIBO
 |  | J26 | Conn_01x10 | Connector_Generic:Conn_01x10 | Connector_PinSocket_2.54mm:PinSocket_1x10_P2.54mm_Vertical | https://jlcpcb.com/partdetail/Hctl-PZ254_1_10_Z_85/C2894933 |  | HAND |  | 0.0942 |  |  | 3A Straight Square Pins 2.5mm 10P 6mm -40â„ƒ~+105â„ƒ 3mm 2.54mm Plugin Black 1x10P Plugin,P=2.54mm Pin Headers ROHS |  | JLCPCB | C2894933 |  |  |  |  | PZ254-1-10-Z-8.5 | HCTL
 |  | J27 | Conn_02x12_Odd_Even | Connector_Generic:Conn_02x12_Odd_Even | PubInv_KiCad_PCB.pretty:PinHeader_2x12_P2.00mm_Vertical_JST | https://www.jst-mfg.com/product/pdf/eng/ePHD.pdf |  | HAND |  | 1000000 |  |  |  |  |  |  | JLCPCB | ?https://jlcpcb.com/partdetail/Jst_SalesAmerica-B24B_PHDSS_B_LF_SN/C160327? |  |  |  |  | B24B-PHDSS
 |  | J28 | Screw_Terminal_01x02 | Connector:Screw_Terminal_01x02 | TerminalBlock_TE-Connectivity:TerminalBlock_TE_282834-2_1x02_P2.54mm_Horizontal | DB128V-5.08-2P-GN-S.pdf |  | HAND |  | 0.1537 |  |  | 1x2P 20A -40â„ƒ~+105â„ƒ 300V Green 12~30 Straight pin 5.08mm 2.5 1 2 Plugin,P=5.08mm Screw terminal ROHS |  | JLCPCB | C918120 |  |  |  |  | DB125-2.54-2P-GN-S | DIBO
 |  | J29 | Conn_01x10 | Connector_Generic:Conn_01x10 | Connector_PinSocket_2.54mm:PinSocket_1x10_P2.54mm_Vertical | https://jlcpcb.com/partdetail/Hctl-PZ254_1_10_Z_85/C2894933 |  | HAND |  | 0.0942 |  |  | 3A Straight Square Pins 2.5mm 10P 6mm -40â„ƒ~+105â„ƒ 3mm 2.54mm Plugin Black 1x10P Plugin,P=2.54mm Pin Headers ROHS |  | JLCPCB | C2894933 |  |  |  |  | PZ254-1-10-Z-8.5 | HCTL
 |  | J30 | Screw_Terminal_01x02 | Connector:Screw_Terminal_01x02 | TerminalBlock_TE-Connectivity:TerminalBlock_TE_282834-2_1x02_P2.54mm_Horizontal | DB128V-5.08-2P-GN-S.pdf |  | HAND |  | 0.1537 |  |  | 1x2P 20A -40â„ƒ~+105â„ƒ 300V Green 12~30 Straight pin 5.08mm 2.5 1 2 Plugin,P=5.08mm Screw terminal ROHS |  | JLCPCB | C918120 |  |  |  |  | DB125-2.54-2P-GN-S | DIBO
 |  | J31 | Screw_Terminal_01x02 | Connector:Screw_Terminal_01x02 | TerminalBlock_TE-Connectivity:TerminalBlock_TE_282834-2_1x02_P2.54mm_Horizontal | DB128V-5.08-2P-GN-S.pdf |  | HAND |  | 0.1537 |  |  | 1x2P 20A -40â„ƒ~+105â„ƒ 300V Green 12~30 Straight pin 5.08mm 2.5 1 2 Plugin,P=5.08mm Screw terminal ROHS |  | JLCPCB | C918120 |  |  |  |  | DB125-2.54-2P-GN-S | DIBO
 |  | J32 | Screw_Terminal_01x02 | Connector:Screw_Terminal_01x02 | TerminalBlock_TE-Connectivity:TerminalBlock_TE_282834-2_1x02_P2.54mm_Horizontal | DB128V-5.08-2P-GN-S.pdf |  | HAND |  | 0.1537 |  |  | 1x2P 20A -40â„ƒ~+105â„ƒ 300V Green 12~30 Straight pin 5.08mm 2.5 1 2 Plugin,P=5.08mm Screw terminal ROHS |  | JLCPCB | C918120 |  |  |  |  | DB125-2.54-2P-GN-S | DIBO
 |  | J33 | Screw_Terminal_01x02 | Connector:Screw_Terminal_01x02 | TerminalBlock_TE-Connectivity:TerminalBlock_TE_282834-2_1x02_P2.54mm_Horizontal | DB128V-5.08-2P-GN-S.pdf |  | HAND |  | 0.1537 |  |  | 1x2P 20A -40â„ƒ~+105â„ƒ 300V Green 12~30 Straight pin 5.08mm 2.5 1 2 Plugin,P=5.08mm Screw terminal ROHS |  | JLCPCB | C918120 |  |  |  |  | DB125-2.54-2P-GN-S | DIBO
 |  | J34 | Screw_Terminal_01x02 | Connector:Screw_Terminal_01x02 | TerminalBlock_TE-Connectivity:TerminalBlock_TE_282834-2_1x02_P2.54mm_Horizontal | DB128V-5.08-2P-GN-S.pdf |  | HAND |  | 0.1537 |  |  | 1x2P 20A -40â„ƒ~+105â„ƒ 300V Green 12~30 Straight pin 5.08mm 2.5 1 2 Plugin,P=5.08mm Screw terminal ROHS |  | JLCPCB | C918120 |  |  |  |  | DB125-2.54-2P-GN-S | DIBO
 |  | JP1 | SolderJumper_3_Bridged12 | Jumper:SolderJumper_3_Bridged12 | Jumper:SolderJumper-3_P1.3mm_Bridged12_RoundedPad1.0x1.5mm | NA |  | DNI |  | 0 |  |  | SolderJumper_3_Bridged12 |  | PublicInvention | NA |  |  |  |  | NA | NA
 |  | JP2 | SolderJumper_3_Bridged12 | Jumper:SolderJumper_3_Bridged12 | Jumper:SolderJumper-3_P1.3mm_Bridged12_RoundedPad1.0x1.5mm | NA |  | DNI |  | 0 |  |  | SolderJumper_3_Bridged12 |  | PublicInvention | NA |  |  |  |  | NA | NA
 |  | JP3 | SolderJumper_3_Bridged12 | Jumper:SolderJumper_3_Bridged12 | Jumper:SolderJumper-3_P1.3mm_Bridged12_RoundedPad1.0x1.5mm | NA |  | DNI |  | 0 |  |  | SolderJumper_3_Bridged12 |  | PublicInvention | NA |  |  |  |  | NA | NA
 |  | JP4 | SolderJumper_3_Bridged12 | Jumper:SolderJumper_3_Bridged12 | Jumper:SolderJumper-3_P1.3mm_Bridged12_RoundedPad1.0x1.5mm | NA |  | DNI |  | 0 |  |  | SolderJumper_3_Bridged12 |  | PublicInvention | NA |  |  |  |  | NA | NA
 |  | JP5 | SolderJumper_3_Bridged12 | Jumper:SolderJumper_3_Bridged12 | Jumper:SolderJumper-3_P1.3mm_Bridged12_RoundedPad1.0x1.5mm | NA |  | DNI |  | 0 |  |  | SolderJumper_3_Bridged12 |  | PublicInvention | NA |  |  |  |  | NA | NA
 |  | JP6 | SolderJumper_3_Bridged12 | Jumper:SolderJumper_3_Bridged12 | Jumper:SolderJumper-3_P1.3mm_Bridged12_RoundedPad1.0x1.5mm | NA |  | DNI |  | 0 |  |  | SolderJumper_3_Bridged12 |  | PublicInvention | NA |  |  |  |  | NA | NA
 |  | JP7 | SolderJumper_3_Bridged12 | Jumper:SolderJumper_3_Bridged12 | Jumper:SolderJumper-3_P1.3mm_Bridged12_RoundedPad1.0x1.5mm | NA |  | DNI |  | 0 |  |  | SolderJumper_3_Bridged12 |  | PublicInvention | NA |  |  |  |  | NA | NA
 |  | JP8 | SolderJumper_3_Bridged12 | Jumper:SolderJumper_3_Bridged12 | Jumper:SolderJumper-3_P1.3mm_Bridged12_RoundedPad1.0x1.5mm | NA |  | DNI |  | 0 |  |  | SolderJumper_3_Bridged12 |  | PublicInvention | NA |  |  |  |  | NA | NA
 |  | JP9 | MAX31850K | Connector_Generic:Conn_01x08 | PubInv_KiCad_PCB:Adafruit_MAX31850K_Module | https://www.adafruit.com/product/1727 |  | HAND |  | 14.95 |  |  | Thermocouple Amplifier with 1-Wire Breakout Board - MAX31850K |  | adafruit | 1727 |  |  |  |  | 1727 | Adafruit
 |  | JP10 | MAX31850K | Control v1-eagle-import:microbuilder_HEADER-1X870MIL | PubInv_KiCad_PCB:Adafruit_MAX31850K_Module | https://www.adafruit.com/product/1727 |  | HAND |  | 14.95 |  |  | Thermocouple Amplifier with 1-Wire Breakout Board - MAX31850K |  | adafruit | 1727 |  |  |  |  | 1727 | Adafruit
 |  | JP11 | SolderJumper_3_Bridged12 | Jumper:SolderJumper_3_Bridged12 | Jumper:SolderJumper-3_P1.3mm_Bridged12_RoundedPad1.0x1.5mm | NA |  | DNI |  | 0 |  |  | SolderJumper_3_Bridged12 |  | PublicInvention | NA |  |  |  |  | NA | NA
 |  | JP12 | SolderJumper_3_Bridged12 | Jumper:SolderJumper_3_Bridged12 | Jumper:SolderJumper-3_P1.3mm_Bridged12_RoundedPad1.0x1.5mm | NA |  | DNI |  | 0 |  |  | SolderJumper_3_Bridged12 |  | PublicInvention | NA |  |  |  |  | NA | NA
 |  | JP13 | SolderJumper_3_Bridged12 | Jumper:SolderJumper_3_Bridged12 | Jumper:SolderJumper-3_P1.3mm_Bridged12_RoundedPad1.0x1.5mm | NA |  | DNI |  | 0 |  |  | SolderJumper_3_Bridged12 |  | PublicInvention | NA |  |  |  |  | NA | NA
 |  | JP14 | SolderJumper_3_Bridged12 | Jumper:SolderJumper_3_Bridged12 | Jumper:SolderJumper-3_P1.3mm_Bridged12_RoundedPad1.0x1.5mm | NA |  | DNI |  | 0 |  |  | SolderJumper_3_Bridged12 |  | PublicInvention | NA |  |  |  |  | NA | NA
 |  | JP15 | MAX31850K | Control v1-eagle-import:microbuilder_HEADER-1X870MIL | PubInv_KiCad_PCB:Adafruit_MAX31850K_Module | https://www.adafruit.com/product/1727 |  | HAND |  | 14.95 |  |  | Thermocouple Amplifier with 1-Wire Breakout Board - MAX31850K |  | adafruit | 1727 |  |  |  |  | 1727 | Adafruit
 |  | JP16 | MAX31855 | Control v1-eagle-import:HEADER-1X676MIL | PubInv_KiCad_PCB:Adafruit_MAX31855_Module | https://www.adafruit.com/product/269 |  | HAND |  | 14.95 |  |  | Thermocouple Amplifier MAX31855 breakout board (MAX6675 upgrade) |  | adafruit | 269 |  |  |  |  | 269 | Adafruit
 |  | JP17 | MAX31855 | Control v1-eagle-import:HEADER-1X676MIL | PubInv_KiCad_PCB:Adafruit_MAX31855_Module | https://www.adafruit.com/product/269 |  | HAND |  | 14.95 |  |  | Thermocouple Amplifier MAX31855 breakout board (MAX6675 upgrade) |  | adafruit | 269 |  |  |  |  | 269 | Adafruit
 |  | JP18 | MAX31855 | Control v1-eagle-import:HEADER-1X676MIL | PubInv_KiCad_PCB:Adafruit_MAX31855_Module | https://www.adafruit.com/product/269 |  | HAND |  | 14.95 |  |  | Thermocouple Amplifier MAX31855 breakout board (MAX6675 upgrade) |  | adafruit | 269 |  |  |  |  | 269 | Adafruit
 |  | JP19 | MCP9600 | Control v1-eagle-import:HEADER-1X970MIL | PubInv_KiCad_PCB:Adafruit_MCP9600_Module | https://www.adafruit.com/product/4101 |  | HAND |  | 15.95 |  |  | Adafruit MCP9600 I2C Thermocouple Amplifier - K, J, T, N, S, E, B and R Type T |  | adafruit | 4101 |  |  |  |  | 4101 | Adafruit
 |  | JP20 | MCP9600 | Control v1-eagle-import:HEADER-1X970MIL | PubInv_KiCad_PCB:Adafruit_MCP9600_Module | https://www.adafruit.com/product/4101 |  | HAND |  | 15.95 |  |  | Adafruit MCP9600 I2C Thermocouple Amplifier - K, J, T, N, S, E, B and R Type T |  | adafruit | 4101 |  |  |  |  | 4101 | Adafruit
 |  | JP21 | MCP9600 | Control v1-eagle-import:HEADER-1X970MIL | PubInv_KiCad_PCB:Adafruit_MCP9600_Module | https://www.adafruit.com/product/4101 |  | HAND |  | 15.95 |  |  | Adafruit MCP9600 I2C Thermocouple Amplifier - K, J, T, N, S, E, B and R Type T |  | adafruit | 4101 |  |  |  |  | 4101 | Adafruit
 |  | MF1 | PCB_BKT_OEDCS_01 | GPAD_SCH_LIB:PCB_GPAD_VER1 | NA | PCB_BKT_OEDCS_01 |  | HAND |  | 1000000 |  |  | PCB_BKT_OEDCS_01 |  | PublicInvention | PCB_BKT_OEDCS_01 |  |  |  | YES | PCB_BKT_OEDCS_01 | PublicInvention
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

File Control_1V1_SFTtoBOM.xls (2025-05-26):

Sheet: Instructions
Instructions for using this spread sheet.
These instructions apply to KiCad 6 and modified for KiCad 7 |  | KiCad BOM generator
Using OpenOffice Calc spread sheet features.
 | This spread sheet is for processing the CSV BOM file generated by KiCad into a form useful for ordering parts and assemblies. It assumes you understand the spread sheet enough to edit the formulas which must change to accommodate the exact number of unique components in a schematic. To the right are screen shots to help you recognize some of the steps described below.
Step# | Description
1 | Using the KiCAD BOM generator “bom_csv_grouped_by_value” generate the “Bill of Materals” CSV file. Rename the file as appropriate to describe the build event.
2 | Open this spread sheet. Save as a new name as appropriate
3 | Open the file from step one OpenOffice CALC by “Text Import” the CSV file in and set for separate by comma delimited fields. This will open in a separate spread sheet. Select the entire contents by clicking on the top cell to the left of “A” column. Copy with <Ctrl>C.
4 | Past into the RAW tab of this spread sheet. To do so, again select the entire RAW sheet by clicking on the top cell to the left of the “A” column. Then Past with <Ctrl>V. Examine the rows till you locate the row “Collated Components:” where several lines below the BOM begins with a row the first cell of which is “item”.
5 | In the BOMNoSort tab on row 5, edit the formula cell by cell to adjust the start of the copy from the row in the RAW tab with the column description cell in the RAW input of the BOM fields. Note the cell copy are not consecutive going to the right an as a consequence the BOMB spread sheet reorders and selects only the information most useful for ordering parts. | OOCalc file import dialog
6 | Copy the BOM_NoSort table into the BOM tab.
7 | Sort the BOM by distributor type (column G) to break out the parts for easy ordering.
8 | Copy the rows with JLCPCB parts from BOM to BOM_JCLPCB tab
9 | Copy the BOM_JLCPCB tab and special past into BOM_JLCPCB_Values for clear text. Save this page as a CSV for example.
 | Use a corresponding process for the PL (Parts List) tab.
 | BOM column headings needed
 |  | Finding the BOM cell A5 and pressing F2 to edit the formula. In this case already set for cell A85
 |  | The formulas in row 5 have been copied down to row 35 which for this BOM includes one empty row of the RAW tab.
 |  | The formulas in PL row 5 have been copied down to row 5 which for this split view of the Parts List includes one empty row of the RAW tab.

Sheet: BOM_NoSort
Selected BOM Report |  |  | A “BOM” has one row per part number.
0 |  |  |  |  |  |  |  |  | Manually Adjust the total part cost summation range |  |  |  | Manually Adjust the total part cost summation range
0 | 0 |  |  |  |  |  |  |  | Total Part Cost= | 0 |  |  | Total Part Cost= | 0
0 | 0 | 0 | 0 | 0 | 0 | 0 | 0 | 0 | 0 | 0 | 0 | 0 | 0 | Extended Cost
0 | 0 | 0 | 0 | 0 | 0 | 0 | 0 | 0 | 0 | 0 | 0 | 0 | 0 | Extended Cost
0 | 0 | 0 | 0 | 0 | 0 | 0 | 0 | 0 | 0 | 0 | 0 | 0 | 0 | Extended Cost
0 | 0 | 0 | 0 | 0 | 0 | 0 | 0 | 0 | 0 | 0 | 0 | 0 | 0 | Extended Cost
0 | 0 | 0 | 0 | 0 | 0 | 0 | 0 | 0 | 0 | 0 | 0 | 0 | 0 | Extended Cost
0 | 0 | 0 | 0 | 0 | 0 | 0 | 0 | 0 | 0 | 0 | 0 | 0 | 0 | Extended Cost
0 | 0 | 0 | 0 | 0 | 0 | 0 | 0 | 0 | 0 | 0 | 0 | 0 | 0 | Extended Cost
0 | 0 | 0 | 0 | 0 | 0 | 0 | 0 | 0 | 0 | 0 | 0 | 0 | 0 | Extended Cost
0 | 0 | 0 | 0 | 0 | 0 | 0 | 0 | 0 | 0 | 0 | 0 | 0 | 0 | Extended Cost
0 | 0 | 0 | 0 | 0 | 0 | 0 | 0 | 0 | 0 | 0 | 0 | 0 | 0 | Extended Cost
0 | 0 | 0 | 0 | 0 | 0 | 0 | 0 | 0 | 0 | 0 | 0 | 0 | 0 | Extended Cost
0 | 0 | 0 | 0 | 0 | 0 | 0 | 0 | 0 | 0 | 0 | 0 | 0 | 0 | Extended Cost
0 | 0 | 0 | 0 | 0 | 0 | 0 | 0 | 0 | 0 | 0 | 0 | 0 | 0 | Extended Cost
0 | 0 | 0 | 0 | 0 | 0 | 0 | 0 | 0 | 0 | 0 | 0 | 0 | 0 | Extended Cost
0 | 0 | 0 | 0 | 0 | 0 | 0 | 0 | 0 | 0 | 0 | 0 | 0 | 0 | Extended Cost
0 | 0 | 0 | 0 | 0 | 0 | 0 | 0 | 0 | 0 | 0 | 0 | 0 | 0 | Extended Cost
0 | 0 | 0 | 0 | 0 | 0 | 0 | 0 | 0 | 0 | 0 | 0 | 0 | 0 | Extended Cost
0 | 0 | 0 | 0 | 0 | 0 | 0 | 0 | 0 | 0 | 0 | 0 | 0 | 0 | Extended Cost
0 | 0 | 0 | 0 | 0 | 0 | 0 | 0 | 0 | 0 | 0 | 0 | 0 | 0 | Extended Cost
0 | 0 | 0 | 0 | 0 | 0 | 0 | 0 | 0 | 0 | 0 | 0 | 0 | 0 | Extended Cost
0 | 0 | 0 | 0 | 0 | 0 | 0 | 0 | 0 | 0 | 0 | 0 | 0 | 0 | Extended Cost
0 | 0 | 0 | 0 | 0 | 0 | 0 | 0 | 0 | 0 | 0 | 0 | 0 | 0 | Extended Cost
0 | 0 | 0 | 0 | 0 | 0 | 0 | 0 | 0 | 0 | 0 | 0 | 0 | 0 | Extended Cost
0 | 0 | 0 | 0 | 0 | 0 | 0 | 0 | 0 | 0 | 0 | 0 | 0 | 0 | Extended Cost
0 | 0 | 0 | 0 | 0 | 0 | 0 | 0 | 0 | 0 | 0 | 0 | 0 | 0 | Extended Cost
0 | 0 | 0 | 0 | 0 | 0 | 0 | 0 | 0 | 0 | 0 | 0 | 0 | 0 | Extended Cost
0 | 0 | 0 | 0 | 0 | 0 | 0 | 0 | 0 | 0 | 0 | 0 | 0 | 0 | Extended Cost
0 | 0 | 0 | 0 | 0 | 0 | 0 | 0 | 0 | 0 | 0 | 0 | 0 | 0 | Extended Cost
0 | 0 | 0 | 0 | 0 | 0 | 0 | 0 | 0 | 0 | 0 | 0 | 0 | 0 | Extended Cost
0 | 0 | 0 | 0 | 0 | 0 | 0 | 0 | 0 | 0 | 0 | 0 | 0 | 0 | Extended Cost
0 | 0 | 0 | 0 | 0 | 0 | 0 | 0 | 0 | 0 | 0 | 0 | 0 | 0 | Extended Cost
0 | 0 | 0 | 0 | 0 | 0 | 0 | 0 | 0 | 0 | 0 | 0 | 0 | 0 | Extended Cost
0 | 0 | 0 | 0 | 0 | 0 | 0 | 0 | 0 | 0 | 0 | 0 | 0 | 0 | Extended Cost
0 | 0 | 0 | 0 | 0 | 0 | 0 | 0 | 0 | 0 | 0 | 0 | 0 | 0 | Extended Cost
0 | 0 | 0 | 0 | 0 | 0 | 0 | 0 | 0 | 0 | 0 | 0 | 0 | 0 | Extended Cost
0 | 0 | 0 | 0 | 0 | 0 | 0 | 0 | 0 | 0 | 0 | 0 | 0 | 0 | Extended Cost
0 | 0 | 0 | 0 | 0 | 0 | 0 | 0 | 0 | 0 | 0 | 0 | 0 | 0 | Extended Cost
0 | 0 | 0 | 0 | 0 | 0 | 0 | 0 | 0 | 0 | 0 | 0 | 0 | 0 | Extended Cost
0 | 0 | 0 | 0 | 0 | 0 | 0 | 0 | 0 | 0 | 0 | 0 | 0 | 0 | Extended Cost
0 | 0 | 0 | 0 | 0 | 0 | 0 | 0 | 0 | 0 | 0 | 0 | 0 | 0 | Extended Cost
0 | 0 | 0 | 0 | 0 | 0 | 0 | 0 | 0 | 0 | 0 | 0 | 0 | 0 | Extended Cost
0 | 0 | 0 | 0 | 0 | 0 | 0 | 0 | 0 | 0 | 0 | 0 | 0 | 0 | Extended Cost
0 | 0 | 0 | 0 | 0 | 0 | 0 | 0 | 0 | 0 | 0 | 0 | 0 | 0 | Extended Cost
0 | 0 | 0 | 0 | 0 | 0 | 0 | 0 | 0 | 0 | 0 | 0 | 0 | 0 | Extended Cost
0 | 0 | 0 | 0 | 0 | 0 | 0 | 0 | 0 | 0 | 0 | 0 | 0 | 0 | Extended Cost
0 | 0 | 0 | 0 | 0 | 0 | 0 | 0 | 0 | 0 | 0 | 0 | 0 | 0 | Extended Cost
0 | 0 | 0 | 0 | 0 | 0 | 0 | 0 | 0 | 0 | 0 | 0 | 0 | 0 | Extended Cost
0 | 0 | 0 | 0 | 0 | 0 | 0 | 0 | 0 | 0 | 0 | 0 | 0 | 0 | Extended Cost
0 | 0 | 0 | 0 | 0 | 0 | 0 | 0 | 0 | 0 | 0 | 0 | 0 | 0 | Extended Cost
0 | 0 | 0 | 0 | 0 | 0 | 0 | 0 | 0 | 0 | 0 | 0 | 0 | 0 | Extended Cost
0 | 0 | 0 | 0 | 0 | 0 | 0 | 0 | 0 | 0 | 0 | 0 | 0 | 0 | Extended Cost
0 | 0 | 0 | 0 | 0 | 0 | 0 | 0 | 0 | 0 | 0 | 0 | 0 | 0 | Extended Cost
0 | 0 | 0 | 0 | 0 | 0 | 0 | 0 | 0 | 0 | 0 | 0 | 0 | 0 | Extended Cost
0 | 0 | 0 | 0 | 0 | 0 | 0 | 0 | 0 | 0 | 0 | 0 | 0 | 0 | Extended Cost
0 | 0 | 0 | 0 | 0 | 0 | 0 | 0 | 0 | 0 | 0 | 0 | 0 | 0 | Extended Cost
0 | 0 | 0 | 0 | 0 | 0 | 0 | 0 | 0 | 0 | 0 | 0 | 0 | 0 | Extended Cost
0 | 0 | 0 | 0 | 0 | 0 | 0 | 0 | 0 | 0 | 0 | 0 | 0 | 0 | Extended Cost
0 | 0 | 0 | 0 | 0 | 0 | 0 | 0 | 0 | 0 | 0 | 0 | 0 | 0 | Extended Cost
0 | 0 | 0 | 0 | 0 | 0 | 0 | 0 | 0 | 0 | 0 | 0 | 0 | 0 | Extended Cost
0 | 0 | 0 | 0 | 0 | 0 | 0 | 0 | 0 | 0 | 0 | 0 | 0 | 0 | Extended Cost
0 | 0 | 0 | 0 | 0 | 0 | 0 | 0 | 0 | 0 | 0 | 0 | 0 | 0 | Extended Cost
0 | 0 | 0 | 0 | 0 | 0 | 0 | 0 | 0 | 0 | 0 | 0 | 0 | 0 | Extended Cost
0 | 0 | 0 | 0 | 0 | 0 | 0 | 0 | 0 | 0 | 0 | 0 | 0 | 0 | Extended Cost
0 | 0 | 0 | 0 | 0 | 0 | 0 | 0 | 0 | 0 | 0 | 0 | 0 | 0 | Extended Cost
0 | 0 | 0 | 0 | 0 | 0 | 0 | 0 | 0 | 0 | 0 | 0 | 0 | 0 | Extended Cost
0 | 0 | 0 | 0 | 0 | 0 | 0 | 0 | 0 | 0 | 0 | 0 | 0 | 0 | Extended Cost
0 | 0 | 0 | 0 | 0 | 0 | 0 | 0 | 0 | 0 | 0 | 0 | 0 | 0 | Extended Cost
0 | 0 | 0 | 0 | 0 | 0 | 0 | 0 | 0 | 0 | 0 | 0 | 0 | 0 | Extended Cost
0 | 0 | 0 | 0 | 0 | 0 | 0 | 0 | 0 | 0 | 0 | 0 | 0 | 0 | Extended Cost

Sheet: BOM
Selected BOM Report |  |  | A “BOM” has one row per part number.
0 |  |  |  |  |  |  |  |  | Manually Adjust the total part cost summation range |  |  |  | Manually Adjust the total part cost summation range
0 | 0 |  |  |  |  |  |  |  | Total Part Cost= | 0 |  |  | Total Part Cost= | 0
0 | 0 | 0 | 0 | 0 | 0 | 0 | 0 | 0 | 0 | 0 | 0 | 0 | 0 | Extended Cost
0 | 0 | 0 | 0 | 0 | 0 | 0 | 0 | 0 | 0 | 0 | 0 | 0 | 0 | Extended Cost
0 | 0 | 0 | 0 | 0 | 0 | 0 | 0 | 0 | 0 | 0 | 0 | 0 | 0 | Extended Cost
0 | 0 | 0 | 0 | 0 | 0 | 0 | 0 | 0 | 0 | 0 | 0 | 0 | 0 | Extended Cost
0 | 0 | 0 | 0 | 0 | 0 | 0 | 0 | 0 | 0 | 0 | 0 | 0 | 0 | Extended Cost
0 | 0 | 0 | 0 | 0 | 0 | 0 | 0 | 0 | 0 | 0 | 0 | 0 | 0 | Extended Cost
0 | 0 | 0 | 0 | 0 | 0 | 0 | 0 | 0 | 0 | 0 | 0 | 0 | 0 | Extended Cost
0 | 0 | 0 | 0 | 0 | 0 | 0 | 0 | 0 | 0 | 0 | 0 | 0 | 0 | Extended Cost
0 | 0 | 0 | 0 | 0 | 0 | 0 | 0 | 0 | 0 | 0 | 0 | 0 | 0 | Extended Cost
0 | 0 | 0 | 0 | 0 | 0 | 0 | 0 | 0 | 0 | 0 | 0 | 0 | 0 | Extended Cost
0 | 0 | 0 | 0 | 0 | 0 | 0 | 0 | 0 | 0 | 0 | 0 | 0 | 0 | Extended Cost
0 | 0 | 0 | 0 | 0 | 0 | 0 | 0 | 0 | 0 | 0 | 0 | 0 | 0 | Extended Cost
0 | 0 | 0 | 0 | 0 | 0 | 0 | 0 | 0 | 0 | 0 | 0 | 0 | 0 | Extended Cost
0 | 0 | 0 | 0 | 0 | 0 | 0 | 0 | 0 | 0 | 0 | 0 | 0 | 0 | Extended Cost
0 | 0 | 0 | 0 | 0 | 0 | 0 | 0 | 0 | 0 | 0 | 0 | 0 | 0 | Extended Cost
0 | 0 | 0 | 0 | 0 | 0 | 0 | 0 | 0 | 0 | 0 | 0 | 0 | 0 | Extended Cost
0 | 0 | 0 | 0 | 0 | 0 | 0 | 0 | 0 | 0 | 0 | 0 | 0 | 0 | Extended Cost
0 | 0 | 0 | 0 | 0 | 0 | 0 | 0 | 0 | 0 | 0 | 0 | 0 | 0 | Extended Cost
0 | 0 | 0 | 0 | 0 | 0 | 0 | 0 | 0 | 0 | 0 | 0 | 0 | 0 | Extended Cost
0 | 0 | 0 | 0 | 0 | 0 | 0 | 0 | 0 | 0 | 0 | 0 | 0 | 0 | Extended Cost
0 | 0 | 0 | 0 | 0 | 0 | 0 | 0 | 0 | 0 | 0 | 0 | 0 | 0 | Extended Cost
0 | 0 | 0 | 0 | 0 | 0 | 0 | 0 | 0 | 0 | 0 | 0 | 0 | 0 | Extended Cost
0 | 0 | 0 | 0 | 0 | 0 | 0 | 0 | 0 | 0 | 0 | 0 | 0 | 0 | Extended Cost
0 | 0 | 0 | 0 | 0 | 0 | 0 | 0 | 0 | 0 | 0 | 0 | 0 | 0 | Extended Cost
0 | 0 | 0 | 0 | 0 | 0 | 0 | 0 | 0 | 0 | 0 | 0 | 0 | 0 | Extended Cost
0 | 0 | 0 | 0 | 0 | 0 | 0 | 0 | 0 | 0 | 0 | 0 | 0 | 0 | Extended Cost
0 | 0 | 0 | 0 | 0 | 0 | 0 | 0 | 0 | 0 | 0 | 0 | 0 | 0 | Extended Cost
0 | 0 | 0 | 0 | 0 | 0 | 0 | 0 | 0 | 0 | 0 | 0 | 0 | 0 | Extended Cost
0 | 0 | 0 | 0 | 0 | 0 | 0 | 0 | 0 | 0 | 0 | 0 | 0 | 0 | Extended Cost
0 | 0 | 0 | 0 | 0 | 0 | 0 | 0 | 0 | 0 | 0 | 0 | 0 | 0 | Extended Cost
0 | 0 | 0 | 0 | 0 | 0 | 0 | 0 | 0 | 0 | 0 | 0 | 0 | 0 | Extended Cost
0 | 0 | 0 | 0 | 0 | 0 | 0 | 0 | 0 | 0 | 0 | 0 | 0 | 0 | Extended Cost
0 | 0 | 0 | 0 | 0 | 0 | 0 | 0 | 0 | 0 | 0 | 0 | 0 | 0 | Extended Cost
0 | 0 | 0 | 0 | 0 | 0 | 0 | 0 | 0 | 0 | 0 | 0 | 0 | 0 | Extended Cost
0 | 0 | 0 | 0 | 0 | 0 | 0 | 0 | 0 | 0 | 0 | 0 | 0 | 0 | Extended Cost
0 | 0 | 0 | 0 | 0 | 0 | 0 | 0 | 0 | 0 | 0 | 0 | 0 | 0 | Extended Cost
0 | 0 | 0 | 0 | 0 | 0 | 0 | 0 | 0 | 0 | 0 | 0 | 0 | 0 | Extended Cost
0 | 0 | 0 | 0 | 0 | 0 | 0 | 0 | 0 | 0 | 0 | 0 | 0 | 0 | Extended Cost
0 | 0 | 0 | 0 | 0 | 0 | 0 | 0 | 0 | 0 | 0 | 0 | 0 | 0 | Extended Cost
0 | 0 | 0 | 0 | 0 | 0 | 0 | 0 | 0 | 0 | 0 | 0 | 0 | 0 | Extended Cost
0 | 0 | 0 | 0 | 0 | 0 | 0 | 0 | 0 | 0 | 0 | 0 | 0 | 0 | Extended Cost
0 | 0 | 0 | 0 | 0 | 0 | 0 | 0 | 0 | 0 | 0 | 0 | 0 | 0 | Extended Cost
0 | 0 | 0 | 0 | 0 | 0 | 0 | 0 | 0 | 0 | 0 | 0 | 0 | 0 | Extended Cost
0 | 0 | 0 | 0 | 0 | 0 | 0 | 0 | 0 | 0 | 0 | 0 | 0 | 0 | Extended Cost
0 | 0 | 0 | 0 | 0 | 0 | 0 | 0 | 0 | 0 | 0 | 0 | 0 | 0 | Extended Cost
0 | 0 | 0 | 0 | 0 | 0 | 0 | 0 | 0 | 0 | 0 | 0 | 0 | 0 | Extended Cost
0 | 0 | 0 | 0 | 0 | 0 | 0 | 0 | 0 | 0 | 0 | 0 | 0 | 0 | Extended Cost
0 | 0 | 0 | 0 | 0 | 0 | 0 | 0 | 0 | 0 | 0 | 0 | 0 | 0 | Extended Cost
0 | 0 | 0 | 0 | 0 | 0 | 0 | 0 | 0 | 0 | 0 | 0 | 0 | 0 | Extended Cost
0 | 0 | 0 | 0 | 0 | 0 | 0 | 0 | 0 | 0 | 0 | 0 | 0 | 0 | Extended Cost
0 | 0 | 0 | 0 | 0 | 0 | 0 | 0 | 0 | 0 | 0 | 0 | 0 | 0 | Extended Cost
0 | 0 | 0 | 0 | 0 | 0 | 0 | 0 | 0 | 0 | 0 | 0 | 0 | 0 | Extended Cost
0 | 0 | 0 | 0 | 0 | 0 | 0 | 0 | 0 | 0 | 0 | 0 | 0 | 0 | Extended Cost
0 | 0 | 0 | 0 | 0 | 0 | 0 | 0 | 0 | 0 | 0 | 0 | 0 | 0 | Extended Cost
0 | 0 | 0 | 0 | 0 | 0 | 0 | 0 | 0 | 0 | 0 | 0 | 0 | 0 | Extended Cost
0 | 0 | 0 | 0 | 0 | 0 | 0 | 0 | 0 | 0 | 0 | 0 | 0 | 0 | Extended Cost
0 | 0 | 0 | 0 | 0 | 0 | 0 | 0 | 0 | 0 | 0 | 0 | 0 | 0 | Extended Cost
0 | 0 | 0 | 0 | 0 | 0 | 0 | 0 | 0 | 0 | 0 | 0 | 0 | 0 | Extended Cost
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

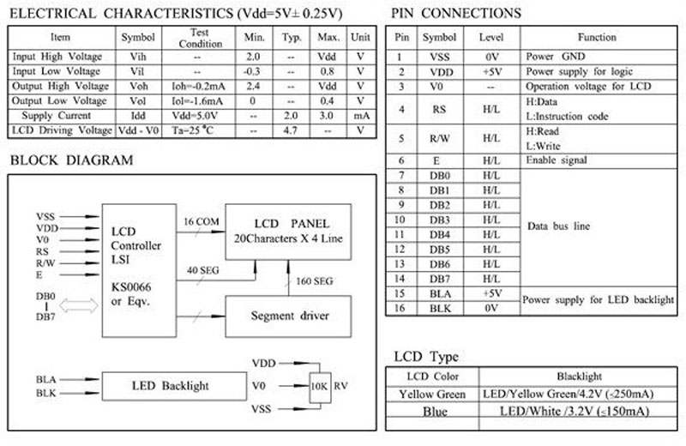
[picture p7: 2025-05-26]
PublicInvention_KiCad_Library/Parts/20x4DisplayElectrical.jpg

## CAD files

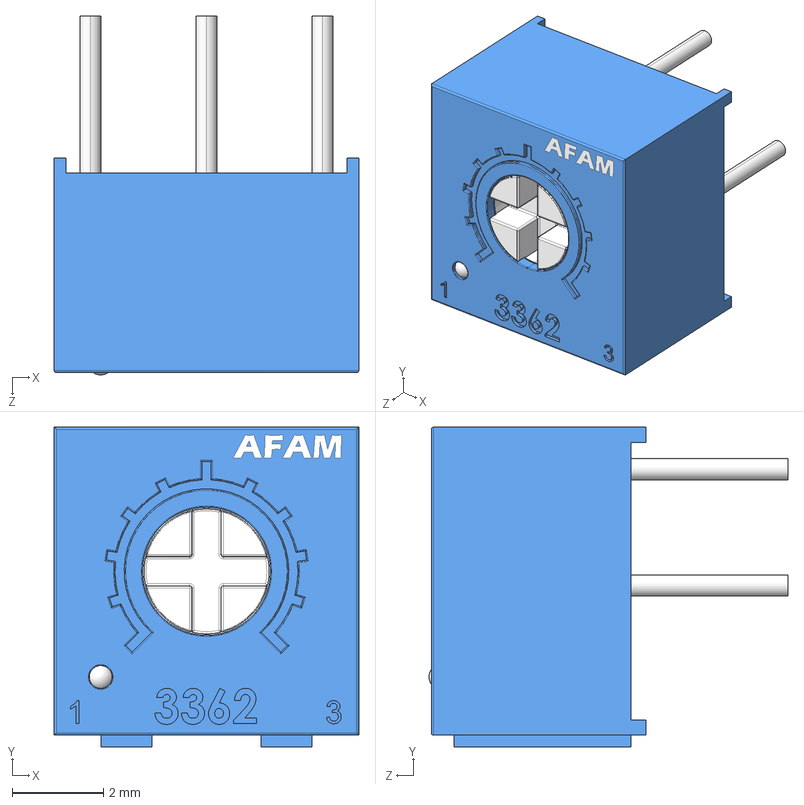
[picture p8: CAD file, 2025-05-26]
PublicInvention_KiCad_Library/Parts/10K, BOURNS 3362P-103LF.STEP
6.66 x 6.99 x 7.85 mm

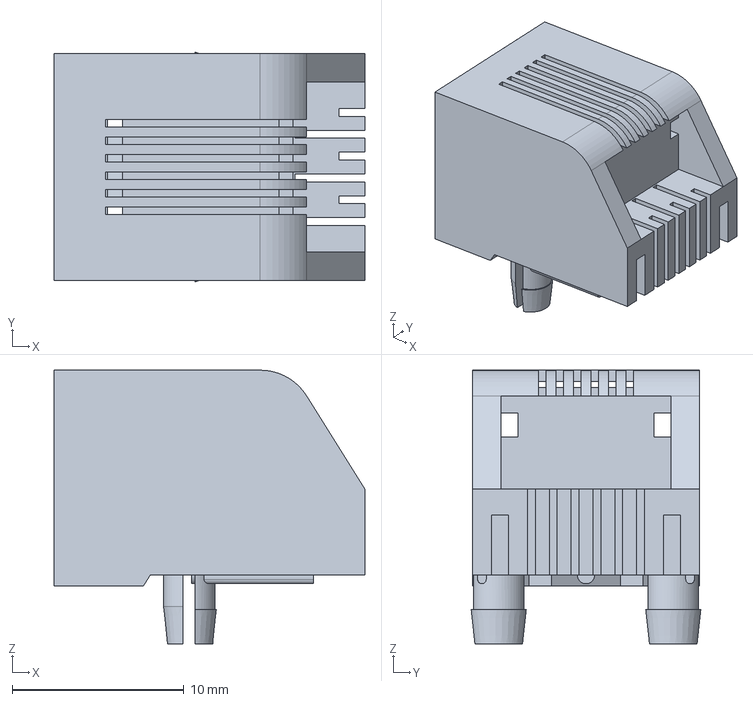
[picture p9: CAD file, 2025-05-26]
PublicInvention_KiCad_Library/Parts/rj11-connectors-6p-1.snapshot.1/Amphenol_54601_RT_ANGLE.step
18.1 x 13.4 x 15.9 mm

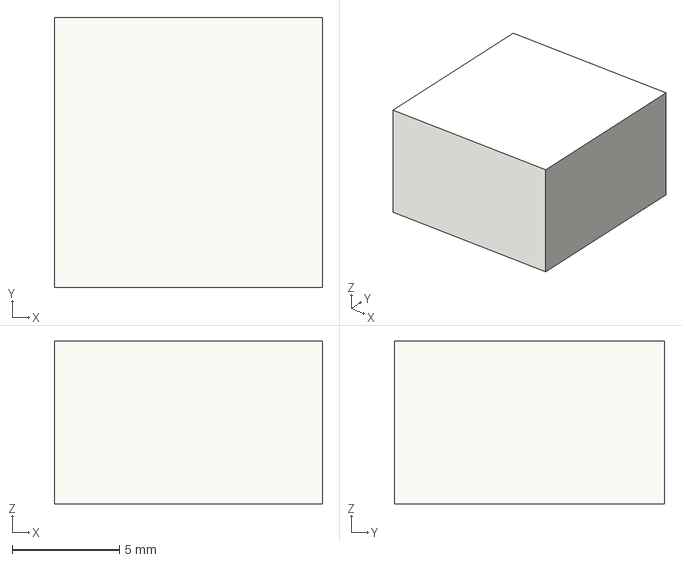
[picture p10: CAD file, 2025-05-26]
PublicInvention_KiCad_Library/Parts/S04B-XASK-1/Cube.step
12.5 x 12.6 x 7.59 mm

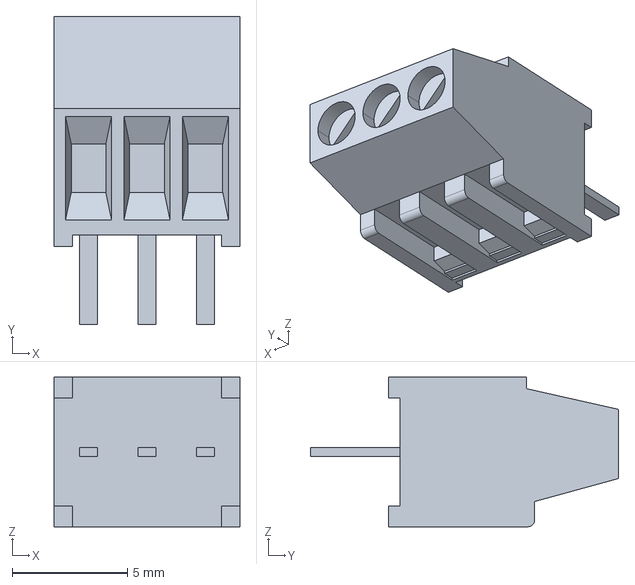
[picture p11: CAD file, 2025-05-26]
PublicInvention_KiCad_Library/Parts/TEConnect/ENG_CVM_CVM_282834-3_C.3d_stp/c-282834-3-c-3d.stp
8.08 x 13.4 x 6.50 mm

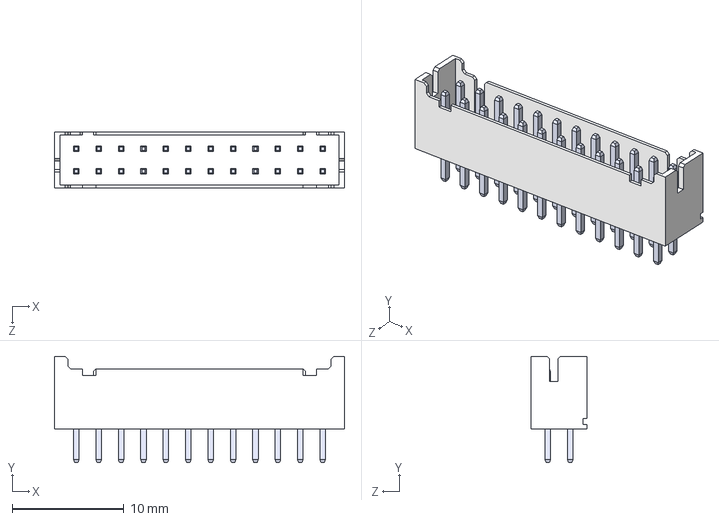
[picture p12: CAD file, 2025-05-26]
resources/B24B/B24B-PHDSS-B-LF--SN---3DModel-STEP-56544.STEP
25.9 x 9.50 x 5.00 mm
BxB-PHDSS_24
pin^BxB-PHDSS ass x 24

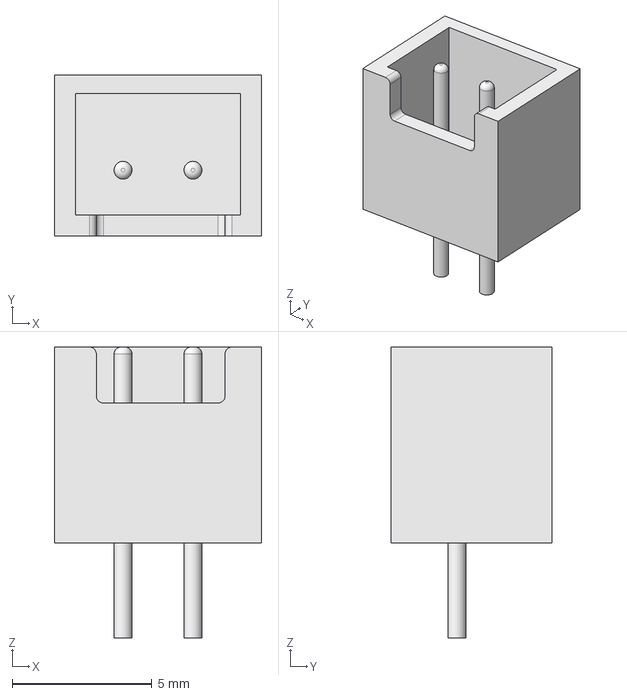
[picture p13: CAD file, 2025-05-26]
resources/B2B-XH-A-GU_MODEL.step
7.40 x 5.75 x 10.4 mm

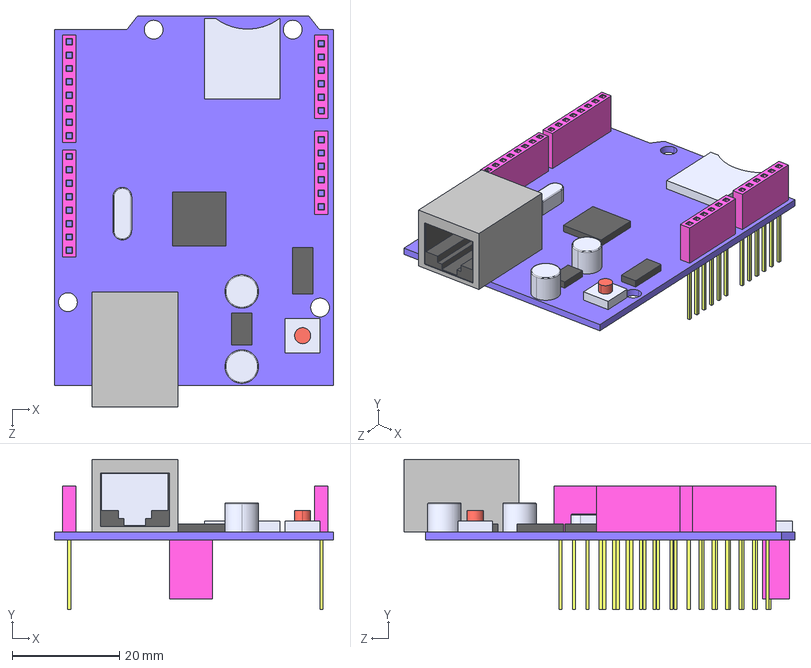
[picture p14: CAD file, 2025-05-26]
resources/Due/Ethernet_shield_Arduino.STEP
52.0 x 28.0 x 72.8 mm

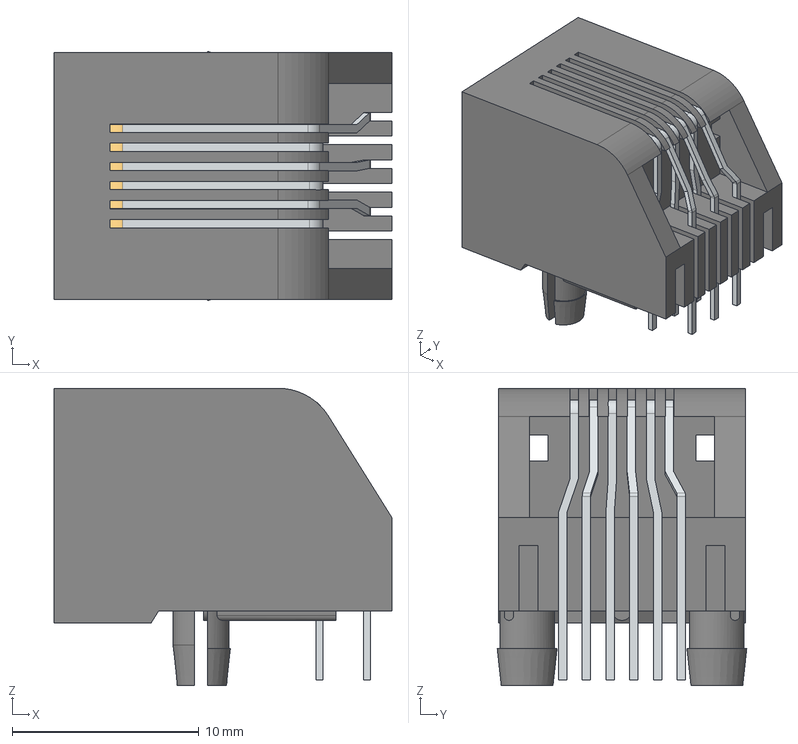
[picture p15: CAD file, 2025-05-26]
PublicInvention_KiCad_Library/Parts/rj11-connectors-6p-1.snapshot.1/rj-6--horiz-tabdown-615006143621 (rev1).stp
18.1 x 13.4 x 15.9 mm

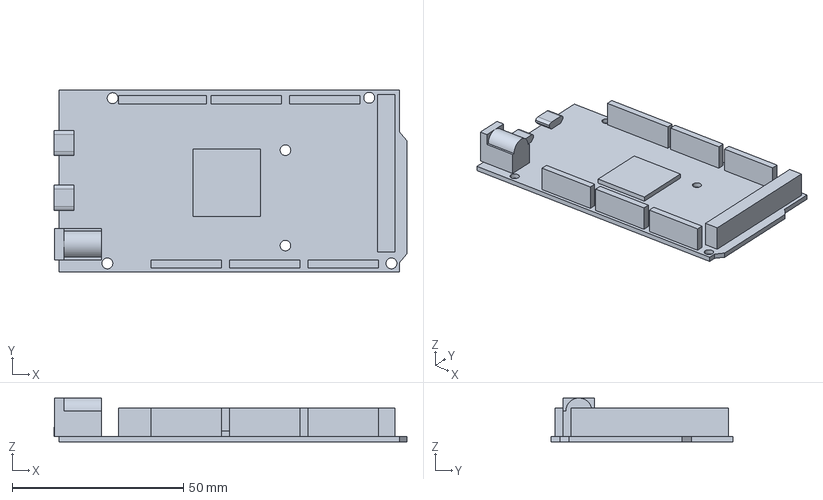
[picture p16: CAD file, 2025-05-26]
resources/Due/Arduino_Due_13571747.stp
103.1 x 53.2 x 12.8 mm

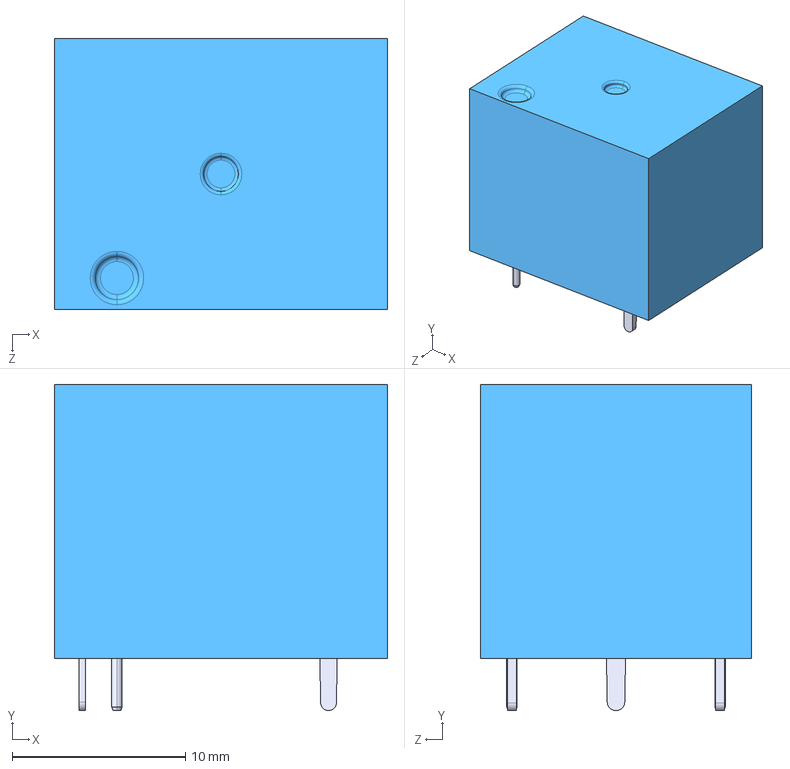
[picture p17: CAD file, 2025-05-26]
resources/SRD-05VDC-SL-C.STEP
19.2 x 18.8 x 15.6 mm

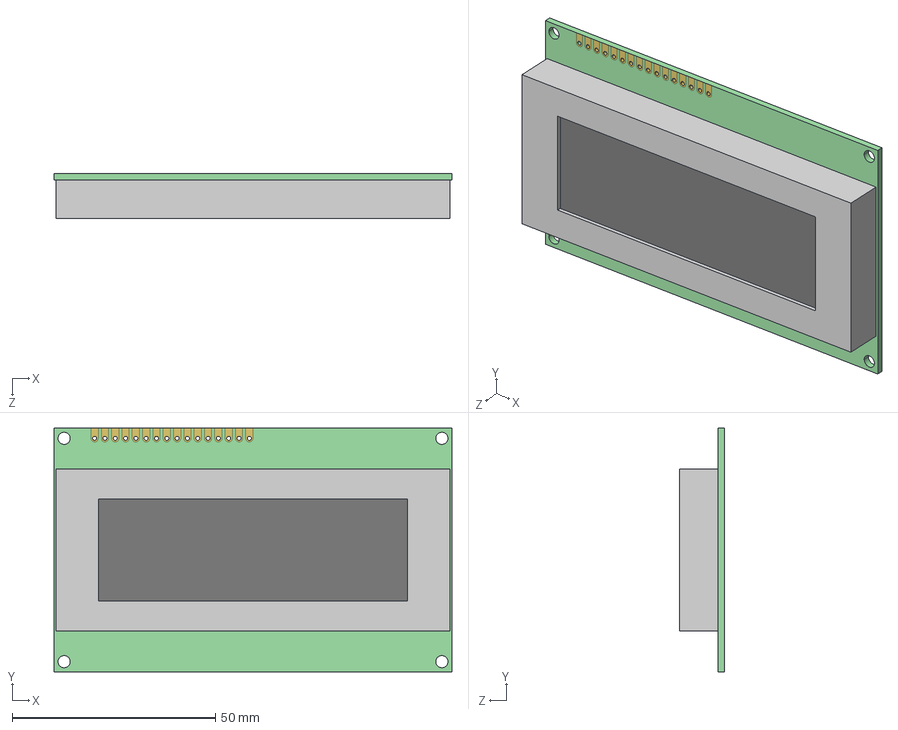
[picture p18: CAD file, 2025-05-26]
PublicInvention_KiCad_Library/Parts/2004A_ap214.STEP
98.0 x 60.0 x 11.1 mm

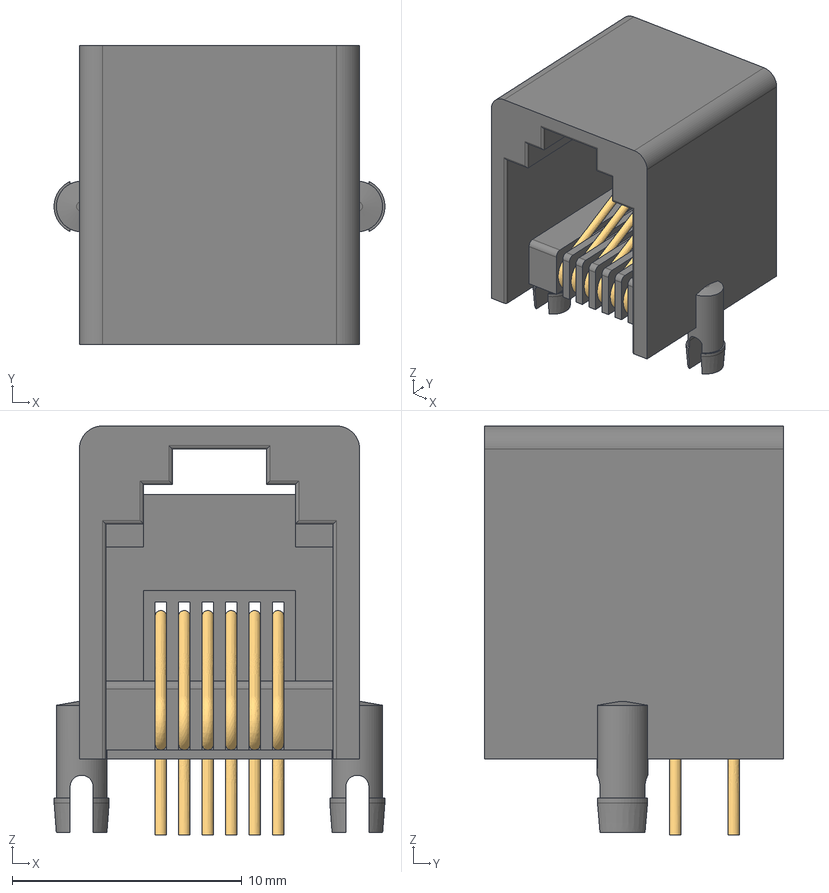
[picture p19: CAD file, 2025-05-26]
PublicInvention_KiCad_Library/Parts/rj11-connectors-6p-1.snapshot.1/rj-69-horiz-615006138421 (rev1).stp
14.4 x 13.0 x 17.8 mm
615006138421_PIN x 3
615006138421_PIN_LONGUE x 3
6150xx138421

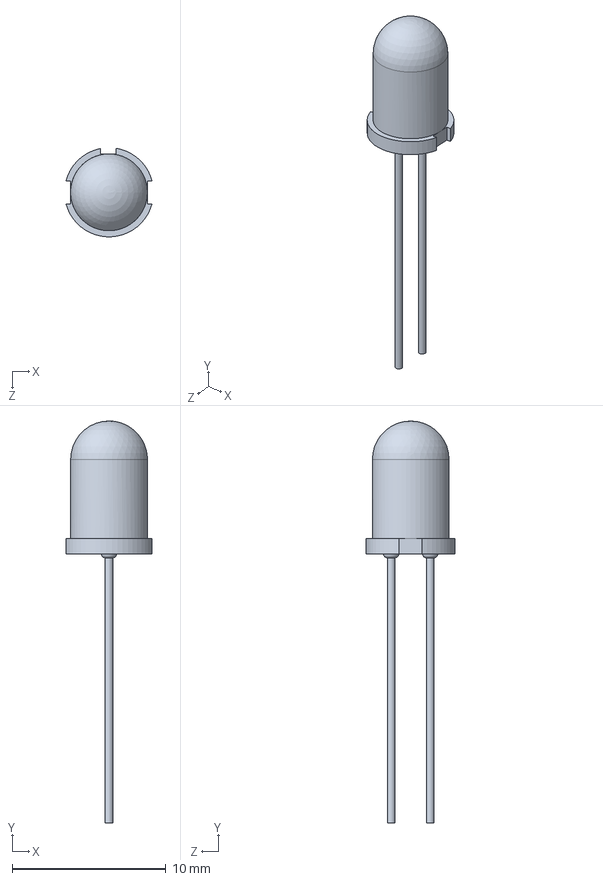
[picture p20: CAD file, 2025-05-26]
PublicInvention_KiCad_Library/Parts/LED 5MM TH WHITE.STEP
5.60 x 26.1 x 5.76 mm

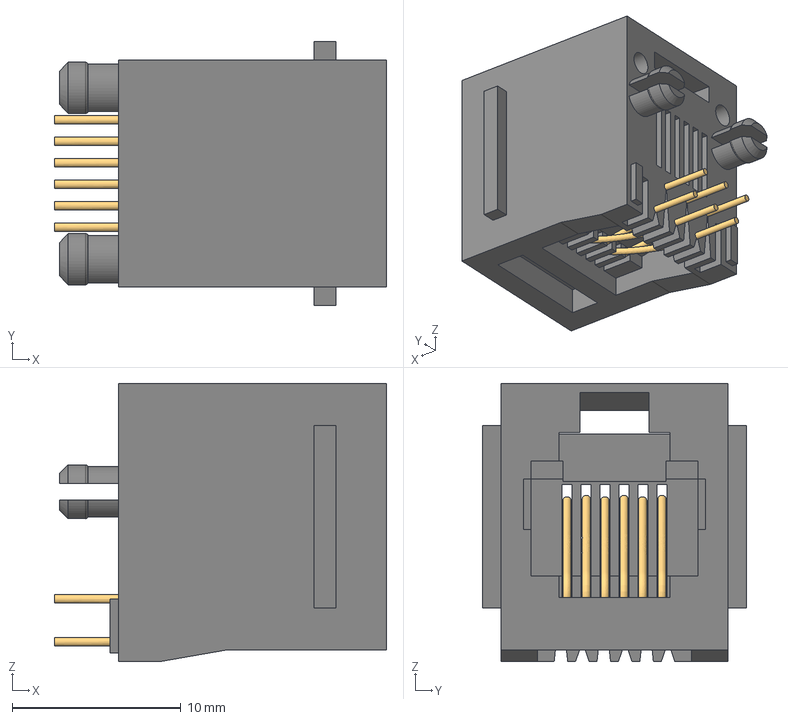
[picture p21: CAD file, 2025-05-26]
PublicInvention_KiCad_Library/Parts/rj11-connectors-6p-1.snapshot.1/rj_6p_615006144121 (rev1).stp
19.7 x 15.7 x 16.5 mm
pin1
pin3
pin5
pin2
pin4
pin6
housing

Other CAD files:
PublicInvention_KiCad_Library/Parts/S04B-XASK-1/first/Cube.step
PublicInvention_KiCad_Library/Parts/USB User Library-10118194.STEP
PublicInvention_KiCad_Library/Parts/12mmx12mm With Green cap.stp
PublicInvention_KiCad_Library/Parts/SOT23.STEP
PublicInvention_KiCad_Library/Parts/94639A702_Off-White Nylon Unthreaded Spacer.STEP
PublicInvention_KiCad_Library/Parts/BarrelJackSMD v3.step
PublicInvention_KiCad_Library/Parts/BarrelJackSMD v3.stl
PublicInvention_KiCad_Library/Parts/Molex_0470531000/0470531000.stp
PublicInvention_KiCad_Library/Parts/NotGood_XKB Connectivity U254-051N-4BH806.step
PublicInvention_KiCad_Library/Parts/TS6-THT-SQ.step
resources/B2B-XH-A-GU_MODEL.FCStd

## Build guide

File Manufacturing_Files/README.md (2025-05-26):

# Discription of these files

The files used to order Control V1 printed wiring assemblies from JLCPCB on about 20230828

* Control v1 bom and placement 28_8_2023 .zip
* Control v1Gerbers 28_8_2023.zip
* bom (3).xls

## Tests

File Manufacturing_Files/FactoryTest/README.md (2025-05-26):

# Factory Test Plan, Control V1.2, Printed Wiring Assembly
Journal of tests for assemblies of January 2025.  
PCB assembly by JLCPCB with some finish work in Maryville TN.  
Fiffteen Assemblies assigned SN 16-30.  

Notes made in issue #TBD during the development of this test plan.

## Resources
12V power supply with current monitor. Color the plug Red. 
Multi meter to measure voltage and resistance.  (Actual Multimeter (EMCO DMR-3800) )  
PC with Arduino IDE to connect to USB programing port of Due  
  

Firmware: https://github.com/PubInv/NASA-MCOG/tree/develop/elec/Control%20Board/Control_1v1/FactoryTest  
Arduino Sketches: 
1. DueWithThreeSSRs
2. GraphicsTest

## Test Procedure
### Before Test, Finish Assembly
The following reworks and changes are required on the assemblies build for JLCPCB order of Control V1.2 in early 2025. 
Notes: All of the JST two pin hearders were found to be incorrecly orentaged bacuse of the "correction" of the footpring and silk screen on V1.2 The connectors for ground pins near the thermocouple amplifier are all ground and so do not need correction however the others must be removed and rotated.  JLCPCB did not have stock of the poly fuse. Other changed were found during factory testing detailed in this list of changes

#### Early 2025 Changes to Assemblies
1. Simply remove J28.
2. Color the connector J11, +12VIn red with a sharpie.
3. Color the connector J12, +24V in black with a sharpie.
4. Remove and rotate 180 degrees connector J11, J12, J13, J25, J30, and J31.
5. Change R106 and R108 from 10K to 20K. This rework is done by unsoldering the existing 10K resistor and rotating it 90 degrees on one pad. Add a second 10K resistor to the now vacant pad and a short wire beween the two resistors. Lee used 30 AWG wire wrap wire.
6. Add a 1 Ohm 0603 SMT resistor at R74 to provide 5V power at the I2C connector J24.
7. Install PolyFuse F801 near the relay.  
  

8. Add an new resistor R186 a 10K on D42 from J8 pin 24 5o pin 30 (GND).   
   
9. DO NOT INSTALL DUE AT THIS TIME, but do install stackable (feed through) headers for the Due connections which make this assembly become a shield for a Due. 

### Unpowered Test of PWA.
To prevent possible damage to units and test equipment, **before** adding power to the assembly make the following tests.

Summary and data capture table

Tester Name ____ F. Lee Erickson ________________
Date of Test _____ 20250130 _____________________

| **Test ID** | 1 | 2 | 3 | 4 | 5 | 6 | | |
|---|---|---|---|---|---|---|---|---|
| **Test Name** | Inspection | +24In In No Short | +12In In No Short | 5VHEAD net | +5V net | +3.3V net | | |
| **Setup** | Inspect correct orientation on polarized parts | Set ohm meter 20M. Com to GND | Set ohm meter 20M. Com to GND | Set ohm meter 20M. Com to GND | Set ohm meter 20M. Com to GND | Set ohm meter 20M. Com to GND | | |
| **Test Location** | | TP20 (J12 Pin 1) | TP 2 (J11 Pin 1) | J8 Pin 1 | J3 Pin 4 | J3 Pin 5 | | |
| **Requirements**  | | > 10K | > 10K | Open or > 1 Meg | Open or > 1 Meg | Open or > 1 Meg | | |
| **Results SN 9**  | D1 and D2 Probably backwards. | 34.6K | 39.8K | Open | 12.1 Meg | 11.7 Meg | | |
| **Results SN 10** | | 34.6K | 39.9K | Open | Open | Open | | |
| **Results SN 11** | | 34.5K | 39.8K | Open | Open | Open | | |
| **Results SN 12** | | 34.6K | 39.8k | Open | 2.4K (Issue #126 #126) | Open | | |
| **Results SN 13** | | | | | | | | |
| **Results SN 14** | | | | | | | | |
| **Results SN 15** | | | | | | | | |
| **Results SN 16** | | | | | | | | |
| **Results SN 17** | | | | | | | | |
| **Results SN 18** | | | | | | | | |
| **Results SN 19** | | | | | | | | |
| **Results SN 20** | | | | | | | | |
| **Results SN 21** | | | | | | | | |
| **Results SN 22** | | | | | | | | |
| **Results SN 23** | | | | | | | | |
| **Results SN 24** | | | | | | | | |
| **Results SN 25** | | | | | | | | |
| **Results SN 26** | | | | | | | | |
| **Results SN 27** | | | | | | | | |
| **Results SN 28** | | | | | | | | |
| **Results SN 29** | | | | | | | | |
| **Results SN 30** | | | | | | | | |
| | | | | | | | | |
| | | | | | | | | |
| | | | | | | | | |

### Program Due with Firmware
Before connecting to the Controller V1.2 Assembly, program the Due with Load the factory test firmware "MAX31850_Tester.ino" 

## Finish Assembly

#### Build Up MAX31850 Thermocouple Amplifier Sub Assemblies
Note that the side of the board to be up has the pads for configuring the addresses of the assemblies. 
Solder the header and screw terminal to the MAX31850 on the correct side.

1. Install the MAC13850 thermocouple amplifier assemblies to the Control V1.1 at JP9, JP10 and JP15.
Add a ?2.5mm? x 10 mm screw with nut as mechanice support and retention.
Observing polarity, connect thermocouples to the MAX31850 amplifire assemblies.
Cut the four on board shunt on each MAX31850 PCB (See image below for where to cut on one).  Measure with multimeter that the shunt to GND is open.


3. Add screws for legs such as 8-32 x 2") with nuts.  These legs are necessary because the long stacking connectors to be installed must not be bent which would happen if the legs were not installed.
4. Solder in the stakcing Due connectors, seven locations.  The long tails must go in the top and through to the bottom
5. Connect the Due to the Controller assembly.  The Due is under the Controller V1.1 assembly as a "shield".
6. Connect the Ethernet W5200 (or similar) sheild on the top of the Controller V1.1

### Apply power. 
Note the +12VIn, the +24VIn and the Stack programable power supply are connected to a switchable outlet switch.  
With the power outlet off, 
Connect the +12VIn power at J11, the RED connector.  
Connect the  +24VIn power at J12.  
Connect SSR simulator LEDS at  SSR1, SSR2, SSR3.  
Connect the Pumping/Standby switch at J801, FAULT LED with resistor at J802, and STANDBY LED with resistor at J803.
Connect the Stack power supply at J10 ( or J27) at this time.

Apply power by switching on the AC power strip.
**Test ID7:** Note current in table on the +12VIn supply current monitor for excessive, above 100 mA.  THIS NUMBER WILL NEED TO BE CHECKED WITH DUE's THAT HAVE NEVER BEEN PROGRAMED.
Check that the BUILDIN_LED ner the LAN Shield and SSR2 and SSR3 connectors is blinking rapidly as an idication that the firmware is running.
Open the Arduino Serial Plotter (<Ctrl> <Shift> <L>) and touch some thermocouples.

### Temperature Measurements for SN 1 to SN15.
For SN16 and beyond the test is moved further below and uses the OEDCS firmware
**Test ID8:** Typical Serial Plotter results. Touching some of the thermocouples to ensure they respond.
Note resutls in table


**Results continued...**
| **Test ID** | 7 | 8 | 9 |
|---|---|---|---|
| **Test Name** | Current, Temperature Only | Check thermocouples | future use |
| **Setup** | In line DC current meter  | Connect three | |
| **Test Location** | Due input | Serial Plolter | |
| **Requirements**  | 85 mA | Three traces | |
| **Results SN 9**  | | OK | |
| **Results SN 10** | 270mA | OK | |
| **Results SN 11** | 200mA | OK | |
| **Results SN 12** | | | |
| **Results SN 13** | | | |
| **Results SN 14** | | | |
| **Results SN 15** | | | |

#### Load and run factory test firmware DueWithThreeSSRs.ino  
Open the Arduino Serial Monitor. Observe the data.  
**Test ID10 ** Observe SSR1, SSR2, SSR3 LED Blinking.  
**Test ID11 ** Observe Mini12864 Display back lit and displaying splash message and four measurements.  
**Test ID12 ** Encoder Rotation Knob is back lit. Rotate the know and observe the serial port reporting changes.  
**Test ID13 ** Encoder knob switch. Press the knob and observer serial port message about shutdown.  
**Test ID14 ** PCB mount SHUT DOWN button. Press the button and observer serial port message about shutdown.  
**Test ID15 ** Observer serial port message about "Link Status: ON"  
**Test ID16 ** Stack Voltage, SKIP after SN15 Observer serial port message about "?????"  
**Test ID17 ** Stack Power,  SKIP after SN15 Observer serial port message about "?????"  
**Test ID18 ** Cumulocity,  SKIP after SN15 Observer serial port message about "?????"  
**Test ID19 ** Reset, Observer serial port message as DUT reboots"  
**Test ID20 ** PCB mount SHUT DOWN button. Press the button and observer the Battery Connection LED lights.  
**Test ID21 ** Pumping/StandBy with to Pumping (Blue LED ON) PCB mount SHUT DOWN button. Press the button and observer the Blower goes to high speed STATUS_LED is on.  
**Test ID22 ** Pumping/StandBy with to Standby (Blue LED off) PCB mount SHUT DOWN button. Press the button and observer the Blower is off, STATUS_LED is oFf.  

**Results ID 10-21 continued...**

| **Test ID** | 10 | 11 | 12 | 13 | 14 | 15 | 16 | 17 | 18 | 19 | 20 | 21 | 22 |
|---|---|---|---|---|---|---|---|---|---|---|---|---|---|
| **Test Name** | SSR1,  SSR2,  SSR3, LED Blink | Mini12864 Display | Encoder Rotation Knob | Encoder knob  switch | PCB button SHUT DOWN | LAN CONNECTION | Stack voltage @ reset < 1V | Stack power to load | Cumulocity reporting | Reset to  safe | Connection @ Battery | Blower | Pump/ Standby |
| **Setup** | | | | | | | | | | | Press  SHUT DOWN | Press  SHUT DOWN | Blue  Light On |
| **Test Location** | | | | | | | | | | | NA | | |
| **Requirements**  | | | | | | Link OK | | | | | Battery  LED | Blower  High  Speed | Blower On When  ShutDown  STATUS_LED  on when  pumping. |
| **Results SN 9**  | OK | | | | | | | | | | NA | | |
| **Results SN 10** | OK | OK | OK | OK | OK | OK | OK | OK | OK | OK | NA | | |
| **Results SN 11** | OK | OK | OK | OK | OK | OK | OK | OK | OK | OK | NA | | |
| **Results SN 12** | | | | | | | | | | | NA | | |
| **Results SN 13** | | | | | | | | | | | NA | | |
| **Results SN 14** | | | | | | | | | | | NA | | |
| **Results SN 15** | | | | | | | | | | | NA | | |
| **Results SN 16** | | | | | | | | | | | | | |
| **Results SN 17** | | | | | | | | | | | | | |
| **Results SN 18** | | | | | | | | | | | | | |
| **Results SN 19** | OK | NA | NA | NA | OK | OK | Return "SL_Power" | NA | NA | NA | OK | OK | |
| **Results SN 20** | | | | | | | | | | | | | |
| **Results SN 21** | | | | | | | | | | | | | |
| **Results SN 22** | | | | | | | | | | | | | |
| **Results SN 23** | | | | | | | | | | | | | |
| **Results SN 24** | | | | | | | | | | | | | |
| **Results SN 25** | | | | | | | | | | | | | |
| **Results SN 26** | | | | | | | | | | | | | |
| **Results SN 27** | | | | | | | | | | | | | |
| **Results SN 28** | | | | | | | | | | | | | |
| **Results SN 29** | | | | | | | | | | | | | |
| **Results SN 30** | | | | | | | | | | | | | |
| | | | | | | | | | | | | | |
| | | | | | | | | | | | | | |
| | | | | | | | | | | | | | |

### Stack Power Supply Control 
With AC power on.

Load the OEDCS firmware into the unit under test.  
For the firmware to report the MAC address, before compiling, set the ETHERNET_REQUIRED define for 1
In the main.cpp file lines 75 and 76 are:
...
#define ETHERNET_REQUIRED 1
//#define ETHERNET_REQUIRED 0 //No ethernet.  FLE
...

Once the fimrware is loaded, open the serial monitor. 
Observe the traffice and note that a Power supply  is reported.  
  
Observe the traffice and note that an IP address is reported.  
  
On serial port monitor confirm device connects to LAN **ID16**.  

#### Set Stack power supply and +24VIn.  
Connect a 1.5K 1/2 wat resistor load on the Stack Power Supply ouput.
With multi meeter observe the voltage on the stack power supply load.  
After observe and record voltage **ID16** after reset it should be 1V the power on voltage.
Send OEDCS serial port commands to set Stack power to load manual.
* s:1
* a:0.1
* w:2.5
Observe and record **ID17** Stack power to load should now be about 12V

### Observe data on Cumulocity  
https://mcogs.us.cumulocity.com/apps/app-builder/index.html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

Observe and report in issue **ID19**. 

### Reset to Safe
Press and hold the reset button.
Observe that the Stack power supply voltage goes to zero.  (IT DID NOT as of 20231218 with TF800A12K)
Observe that the blower stops.
Observe that the SSR LEDs go off.
Recorde results in test issue **ID19**  

### Capture MAC, Send for Server Setup
After reset and connection to a LAN the Serial Monitor report displays the device MAC address. Catpure to the table below.

| **Unite Serial Number** | **MAC Address** | **Note** |
|---|---|---|
| 1 | FE:ED:1B:70:08:77 | |
| 2 | FE:ED:10:69:73:70 | |
| 3 | NA | |
| 4 | NA | |
| 5 | NA | |
| 9 | FE:ED:1D:70:05:6D | |
| 10 | FE:ED:12:71:06:65 | |
| 11 | FE:ED:16:6B:72:67 | |
| 12 | FE:ED:17:73:0E:69 | |
| 13 | | |
| 15 | ?? | |
| 16 | FE:ED:74:66:03:6E | |
| 17 | FE:ED:16:73:00:65 | |
| 18 | FE:ED:13:70:06:6D | |
| 19 | FE:ED:1D:70:00:6D | |
| 20 | FE:ED:74:66:03:67 | |
| 21 | FE:ED:10:73:00:6F |  FAILED? |
| 22 | NA | |
| 23 | NA | |
| 24 | NA | |
| 25 | NA | |
| 26 | NA | |
| 27 | NA | |
| 28 | NA | |
| 29 | NA | |
| 30 | NA | |

At end of shift send all new MAC Addresses for addition ot the server.

### Temperature Measurements.
**Test ID8:** 
Observe on Serial monitor that two thermocouples report abmiant temprature.

Touching some of the thermocouples to ensure they respond.
Note resutls in table on colum 8

**Results continued...**
| **Test ID** | 7 | 8 | 9 |
|---|---|---|---|
| **Test Name** | Current, Temperature Only | Check thermocouples | future use |
| **Setup** | In line DC current meter  | Connect three | |
| **Test Location** | Due input | Serial Plolter | |
| **Requirements**  | 85 mA | Three traces | |
| **Control V1.2**  | Skip test | Post Heater/Post Stack | |
| **Results SN 16** | NA | Not captured | |
| **Results SN 17** | NA | Not captured | |
| **Results SN 18** | NA | Post Heater C: 20.25 Post Getter C: NA Post Stack  C: 20.50 | |
| **Results SN 19** | NA | Not captured | |
| **Results SN 20** | NA | Post Heater C: 21.75 Post Getter C: NA Post Stack  C: 23.25 | |
| **Results SN 21** | NA | | |
| **Results SN 22** | NA | | |
| **Results SN 23** | NA | | |
| **Results SN 24** | NA | | |
| **Results SN 25** | NA | | |
| **Results SN 26** | NA | | |
| **Results SN 27** | NA | | |
| **Results SN 28** | NA | | |
| **Results SN 29** | NA | | |
| **Results SN 30** | NA | | |
| | | | |
| | | | |
| | | | |

### End of Test
Power off the unit under test.
Apply a green permanet lable near the PubInv logo.

## Rejoice another great OEDCS has been born!

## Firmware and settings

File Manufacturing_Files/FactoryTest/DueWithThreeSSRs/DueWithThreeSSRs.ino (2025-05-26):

/* Program: DueWithThreeSSRs
  Tests the three SSR drive circuits on the Control V1.2 assembly
  Tests the SHUT DOWN switch
  Tests four power supplies, 24V, 12V, AUX1 and AUX2.
  Setup:
  Connect the +12V batter to TBD.
  Connect the progrmable current supply at J10
  Connect an LED with series resistor at J13, J30 and J31. Pin 1 is positive and Pin 2 is ground.
  Series resistor should limit current from +24V for LED.
  SSR1 and SSR2 flash independently.
  Press switch S2, "SHUT DOWN" to turn on the SSR3 LED.
  Ethernet link status reported on serial monitor.
  Read voltages and display during setup before the long power supply setup.
  Note the power supply test takes about 38 seconds.
*/

#define COMPANY_NAME "pubinv.org "
#define PROG_NAME "OEDCS_Factory_Test V1.2"
#define VERSION ";_Rev_0.7"                         // Report UID and MAC
#define DEVICE_UNDER_TEST "Hardware:_Control_V1.2"  //A model number
#define LICENSE "GNU Affero General Public License, version 3 "

#define BAUD_RATE 115200
//

#include <LiquidCrystal_I2C.h>
#define ADDRESS_LCD_MARYVILLE 0x27
#define COLUMNs_LCD_MARYVILLE 20
#define ROWs_LCD_MARYVILLE 4
LiquidCrystal_I2C lcd(ADDRESS_LCD_MARYVILLE, COLUMNs_LCD_MARYVILLE, ROWs_LCD_MARYVILLE);  // set the LCD address to 0x27 for a 16 chars and 2 line display


#include <SPI.h>
#include <Ethernet.h>
#include <MQTT.h>

byte mac[] = { 0xDE, 0xAD, 0xBE, 0xEF, 0xFE, 0xED };
byte ip[] = { 192, 168, 1, 177 };  // <- change to match your network


EthernetClient net;
MQTTClient client;

//MQTT Connect
void connect() {
  Serial.print("connecting...");
  while (!client.connect("PubInv", "public", "public")) {
    Serial.print(".");
    delay(1000);
  }
  Serial.println("\nMQTT connected!");
  // client.subscribe("/hello");
  // client.unsubscribe("/hello");
}

void messageReceived(String &topic, String &payload) {
  Serial.println("incoming: " + topic + " - " + payload);

  // Note: Do not use the client in the callback to publish, subscribe or
  // unsubscribe as it may cause deadlocks when other things arrive while
  // sending and receiving acknowledgments. Instead, change a global variable,
  // or push to a queue and handle it in the loop after calling `client.loop()`.
}

#define ETHERNET_CS 10  //HIGH->Enabled, LOW->Disabled
int link_status;

long previousLinkMillis = 0;
const long LINK_TIME = 1500;  // One and 1/2 second.

const int SET_BLOWER_LOW = 220;
//const int SET_BLOWER_MID = 128;  // Medium
const int SET_BLOWER_HIGH = 20;

//Check power supplies. Reports status on serial port, OLED display.
class PowerSense {
  // Class Member Variables
  // These are initialized at startup
  int ADCinPin;                  // the number of the ADC pin
  long ReadPeriod;               // milliseconds of on-time
  unsigned long previousMillis;  // will store last time ADC was read
  String my_pinName;
  float my_R1;
  float my_R2;
  float voltage;
  int my_offsetX = 0;
  int my_offsetY = 41;  //Benieth center

  // Constructor - creates a Flasher
  // and initializes the member variables and state
public:
  PowerSense(const String pinName, int pin, long period, float R1 = 10000, float R2 = 24700, int offsetX = 0, int offsetY = 0) {
    ADCinPin = pin;
    previousMillis = millis();
    ReadPeriod = period;
    my_pinName = pinName;
    my_R1 = R1;
    my_R2 = R2;
    voltage = 0;
    my_offsetX = offsetX;
    my_offsetY = offsetY;
  }

  void Update() {
    // check to see if it's time to change the state of the LED
    unsigned long currentMillis = millis();
    if (currentMillis - previousMillis >= ReadPeriod) {
      previousMillis = currentMillis;  // Remember the time

      //Force ADCinPin low so that if floating it will read low for the test below.
      // pinMode(ADCinPin, OUTPUT);
      // digitalWrite(ADCinPin, LOW);
      // pinMode(ADCinPin,INPUT);
      // delay(100)    ;

      voltage = analogRead(ADCinPin) * 3.3 * (my_R1 + my_R2) / (1023 * my_R2);  // RAW Read of the ADC
      Serial.print(my_pinName);                                                 //
      Serial.print(": ");                                                       //
      Serial.println(voltage);                                                  // RAW Read of the ADC
    }
  }
};  //end PowersSense

class Flasher {
  // Class Member Variables
  // These are initialized at startup
  int ledPin;    // the number of the LED pin
  long OnTime;   // milliseconds of on-time
  long OffTime;  // milliseconds of off-time

  // These maintain the current state
  int ledState;                  // ledState used to set the LED
  unsigned long previousMillis;  // will store last time LED was updated

  // Constructor - creates a Flasher
  // and initializes the member variables and state
public:
  Flasher(int pin, long on, long off) {
    ledPin = pin;
    pinMode(ledPin, OUTPUT);

    OnTime = on;
    OffTime = off;

    ledState = LOW;
    previousMillis = 0;
  }

  void Update() {
    // check to see if it's time to change the state of the LED
    unsigned long currentMillis = millis();

    if ((ledState == HIGH) && (currentMillis - previousMillis >= OnTime)) {
      ledState = LOW;                  // Turn it off
      previousMillis = currentMillis;  // Remember the time
      digitalWrite(ledPin, ledState);  // Update the actual LED
    } else if ((ledState == LOW) && (currentMillis - previousMillis >= OffTime)) {
      ledState = HIGH;                 // turn it on
      previousMillis = currentMillis;  // Remember the time
      digitalWrite(ledPin, ledState);  // Update the actual LED
    }
  }
};

void UpdateEthernet() {
  // check to see if it's time to update LAN Link status
  unsigned long currentMillis = millis();

  if (((currentMillis - previousLinkMillis) >= LINK_TIME) || (currentMillis < previousLinkMillis)) {
    previousLinkMillis = currentMillis;
    Serial.println("Checking LAN.");
    //FLE    digitalWrite(ETHERNET_CS, LOW);  // select ethernet mode
    link_status = Ethernet.linkStatus();
    //      delay(1000);  // Hold the splash screen a second
    auto link = Ethernet.linkStatus();
    //      delay(1000);  // Hold the splash screen a second
    digitalWrite(ETHERNET_CS, HIGH);  // deselect ethernet mode
    Serial.print("Link status: ");
    lcd.setCursor(0, 2);
    lcd.print("Link status: ");

    switch (link_status) {
      case Unknown:
        Serial.println("Unknown");
        lcd.setCursor(12, 2);
        lcd.print("Unknown");
        break;
      case LinkON:
        Serial.println("ON");
        lcd.setCursor(12, 2);
        lcd.print("ON     ");
        break;
      case LinkOFF:
        Serial.println("OFF");
        lcd.setCursor(12, 2);
        lcd.print("OFF   ");
        break;
    }
  }  // update time.
}


// Resistive dividers Vin = Vadc*3.3/1032 *(R1+R1)/R2
//Read every two seconds
//              Signal name, Pin number, R1, R2, Xoffset, Yoffset
//        PowerSense(const String pinName, int pin, long period, float R1 = 10000, float R2 = 24700, int offsetX = 0, int offsetY = 0)
PowerSense SENSE_24V("+24V ", 1, 10000, 40000, 4700, 0, 50);     //Read A1. R101+R105+R106, R102.
PowerSense SENSE_12V("+12V ", 2, 10000, 40000, 10000, 64, 50);   //Read A2. R103+R107+R108, R104.
PowerSense SENSE_AUX1("AUX1 ", 3, 10000, 10000, 14700, 0, 60);   //Read A3. R123, R124+R125.
PowerSense SENSE_AUX2("AUX2 ", 6, 10000, 10000, 14700, 64, 60);  //Read A6 R126, R127+R128.

//Control V1.1 signal pin names
#define SSR1 51
#define SSR2 52
#define SSR3 53
#define SHUT_DOWN 49
// #define LED_RED 43
// #define LED_BLUE 44
// #define LED_GREEN 45
//Front Panel LEDs and switches
#define FAULT_LED 43
#define STATUS_LED 44
#define ENC_SW 42

#define nFAN1_PWM 9       // The pin D9 for driving the Blower.
#define BLOWER_ENABLE 22  // The pin D22 for Enable 24V to the Blower.

/*(GPIO HIGH, Battery engaged, GPIO LOW, battery disengaged; when GPIO LOW unit will shut off when front
power switch is toggled)  */
#define KEEP_ALIVE 45  // The pin D45 for the control to the relay which when active high connects Standby Battery


// Programable Power Supply Enable
#define PS1_EN 23
#define PS2_EN 8


//Flasher to exercise the SSRs pins and the Building LED.
Flasher led0(13, 100, 400);    //Pins for Control V1.1
Flasher led1(SSR1, 100, 400);  //Pins for Control V1.1
Flasher led2(SSR2, 350, 350);
Flasher led3(FAULT_LED, 300, 400);
Flasher led4(STATUS_LED, 375, 400);
//Flasher led3(SSR3, 150, 350);

//Tests for press of switch, "SHUT DOWN". Turns OFF the SSR3 LED
void updateSHUTDOWN() {
  if (digitalRead(SHUT_DOWN) == LOW) {
    Serial.println("Shutdown button pressed");
    digitalWrite(SSR3, LOW);
    analogWrite(nFAN1_PWM, SET_BLOWER_HIGH);  // Set for high
    digitalWrite(KEEP_ALIVE, HIGH);           // TUrn on Keep Alive.
    delay(500);
  } else {
    digitalWrite(SSR3, HIGH);
    analogWrite(nFAN1_PWM, SET_BLOWER_LOW);  // Set for low
    digitalWrite(KEEP_ALIVE, LOW);           // TUrn off Keep Alive.
  }
}  //end update shutdown button


bool updatePowerMonitor(void) {
  //Analog read of the +24V expected about 3.25V at ADC input.
  // SENSE_24V on A1.
  // Full scale is 1023, ten bits for 3.3V.
  //30K into 4K7
  const long FullScale = 1023;
  const float percentOK = 0.75;
  const long R1 = 10000;
  const long R2 = 24700;
  const float Vcc = 3.3;
  bool powerIsGood = false;
  //int lowThreshold24V = (24 * (R2 / (R1 + R2)) / Vcc) * FullScale * percentOK;  //1023 * 3 / 4;
  //  int lowThreshold24V = (24 * (24700 / (10000 + 24700)) / 3.3) * 1023.0 * 3.0 / 4.0;  //1023 * 3 / 4;
  int lowThreshold24V = 600;  // Typical is 790 so use about 3/4
  const long POWER_MONITOR_TIME = 2000;
  static long previousPowerMillis = 0;

  long currentMillis = millis();

  if (((currentMillis - previousPowerMillis) >= POWER_MONITOR_TIME) || (currentMillis < previousPowerMillis)) {
    previousPowerMillis = currentMillis;
    Serial.print("analogRead(A1)= ");
    Serial.println(analogRead(A1));

    Serial.print("lowThreshold24V= ");
    Serial.println(lowThreshold24V);

    // pinMode(A1, OUTPUT);    //Force A1 low so that if floating it will read low for the lowThreshold24V test below
    // digitalWrite(A1, LOW);
    // pinMode(A1, INPUT);
    int read24V = analogRead(A1);
    if (read24V > lowThreshold24V) {
      Serial.println("24V power OK");
      powerIsGood = true;
      return true;
    } else {
      Serial.print("Bad 24V power = ");
      Serial.println(int((3.3 * read24V) / 1023));
      powerIsGood = false;
      return false;
    }
  }
}
class PSU {
  // #define ADDRESS 0x04
#define ADDRESS 0x00
  //#define MYDELAY 500
#define MYDELAY 10
  uint8_t error = 0;       // error
  char manuf[17];          // INFO 0
  char model[17];          // INFO 1
  char voltage_string[5];  // INFO 2
  char revision[5];        // INFO 3
  char manuf_date[9];      // INFO 4
  char serial[17];         // INFO 5
  char country[17];        // INFO 6
  uint16_t rate_voltage;   //50-51
  uint16_t rate_current;   //52-53
  uint16_t max_voltage;    //54-55
  uint16_t max_current;    //56-57
  uint16_t out_voltage;    //60-61
  uint16_t out_current;    //62-63
  uint8_t temp;            //68
  uint8_t status0;         //6C
  uint8_t status1;         //6F
  uint16_t set_voltage;    // 70-71 r/w
  uint16_t set_current;    // 72-73 r/w
  uint8_t control;         //  7C  r/w
  uint8_t on_off;
  String serial1Buffer;
public:
  int evalResponse() {
    bool validEntry = true;
    char buff[255];

    uint8_t c = 0;
    //while( validEntry)

    while (validEntry) {
      c = Serial1.readBytesUntil('\n', buff, sizeof buff);
      if (c == 3 && (buff[0] == '=' && buff[1] == '>')) {
        // Serial.println("Command executed/recieved successfully.");
        error = 0;
      }
      if (c == 3 && (buff[0] == '?' && buff[1] == '>')) {
        Serial.println("Command error, not accepted.");
        validEntry = false;
        error = 1;
      }
      if (c == 3 && (buff[0] == '!' && buff[1] == '>')) {
        Serial.println("Command correct but execution error (e.g. parameters out of range).");
        validEntry = false;
        error = 2;
      } else {
        validEntry = false;
        //return 0;
      }
    }
    return 1;
  }

  int setPS_Addr(uint8_t addr) {
    Serial1.print("ADDS ");
    Serial1.print(addr);
    Serial1.print("\r\n");
    delay(50);
    return evalResponse();
  }

  int setPS_Val(uint8_t addr, const char *loc, const char *val) {
    if (!setPS_Addr(addr)) {
      Serial.println("didn't set address");
      return 0;
    }

    Serial1.print(loc);
    Serial1.print(' ');
    Serial1.print(val);
    Serial1.print("\r\n");
    delay(100);
    char b[5];
    int c = Serial1.readBytesUntil('\n', b, sizeof b);
    if (c != 3 || b[0] != '=' || b[1] != '>') return 0;
    return 1;
  }

  int setPS_GlobOnOff(uint8_t addr, const char *val) {
    if (strcasecmp(val, "on") == 0) val = "1";
    else val = "0";
    return setPS_Val(addr, "GLOB", val);
  }

  int setPS_OnOff(uint8_t addr, const char *val) {
    if (strcasecmp(val, "on") == 0) val = "1";
    else val = "0";
    return setPS_Val(addr, "POWER", val);
  }

  int setPS_Voltage(uint8_t addr, uint16_t volts) {
    char b[7];
    snprintf(b, sizeof b, "%4.1f", volts / 100.0);
    return setPS_Val(addr, "SV", b);
  }

  int setPS_Current(uint8_t addr, uint16_t amps) {
    char b[7];
    snprintf(b, sizeof b, "%4.1f", amps / 100.0);
    return setPS_Val(addr, "SI", b);
  }

  // TODO: This is untested
  int setPS_GCurrent(uint8_t addr, uint16_t amps) {
    char b[7];
    snprintf(b, sizeof b, "%4.1f", amps / 100.0);
    return setPS_Val(addr, "GSI", b);
  }

  char *getPS_Val(uint8_t addr, const char *val) {
    static char rval[250];
    static char b[50];
    rval[0] = '\0';
    b[0] = '\0';
    if (!setPS_Addr(addr)) {
      Serial.println("didn't set address");
      return 0;
    }
    int c = 0;
    Serial1.print(val);
    Serial1.print("\r\n");
    delay(100);
    c = Serial1.readBytesUntil('\n', b, sizeof b);
    b[c - 1] = '\0';

    for (int i = 0; i < 5; i++) {
      if (b[0] != '=' && b[1] != '>') {
        strcat(rval, b);
      }
      if (b[0] == '?' && b[1] == '>') {
        Serial.println("Command error, not accepted.");
      }
      if (b[0] == '!' && b[1] == '>') {
        Serial.println("Command correct but execution error (e.g. parameters out of range).");
      }
      delay(10);
      c = Serial1.readBytesUntil('\n', b, sizeof b);
      b[c - 1] = '\0';
    }
    return rval;
  }

  void getPS_Manuf(int addr) {
    char *r = getPS_Val(addr, "INFO 0");
    strncpy(manuf, r, sizeof manuf);
    Serial.print("PS Manufacturier= ");
    Serial.println(manuf);
  }

  void getPS_Model(int addr) {
    char *r = getPS_Val(addr, "INFO 1");
    strncpy(model, r, sizeof model);
  }

  void getPS_VoltageString(int addr) {
    char *r = getPS_Val(addr, "INFO 2");
    strncpy(voltage_string, r, sizeof voltage_string);
  }

  void getPS_Revision(int addr) {
    char *r = getPS_Val(addr, "INFO 3");
    strncpy(revision, r, sizeof revision);
  }

  void getPS_ManufDate(int addr) {
    char *r = getPS_Val(addr, "INFO 4");
    strncpy(manuf_date, r, sizeof manuf_date);
  }

  void getPS_Serial(int addr) {
    char *r = getPS_Val(addr, "INFO 5");
    strncpy(serial, r, sizeof serial);
  }

  void getPS_Country(int addr) {
    char *r = getPS_Val(addr, "INFO 6");
    strncpy(country, r, sizeof country);
  }
  //12.00V 66.67A
  void getPS_RateVoltage(int addr) {
    char *r = getPS_Val(addr, "RATE?");
    char b[20];
    strncpy(b, r, sizeof b);
    char *ptr = NULL;
    rate_voltage = -1;
    if ((ptr = strchr(b, ' '))) {
      ptr = strchr(b, 'V');
      *ptr = '\0';
      rate_voltage = int(atof(b) * 100);
    }
  }

  void getPS_RateCurrent(int addr) {
    char *r = getPS_Val(addr, "RATE?");
    char b[20];
    strncpy(b, r, sizeof b);
    char *ptr = NULL;
    char *ptr_2 = NULL;
    rate_current = -1;
    if ((ptr = strchr(b, ' '))) {
      ptr_2 = strchr(ptr, 'A');
      *ptr_2 = '\0';
      rate_current = int(atof(ptr + 1) * 100);
    }
  }

  void getPS_OnOff(int addr) {
    char *r = getPS_Val(addr, "POWER 2");
    switch (r[0]) {
      case '0': on_off = 0; break;
      case '1': on_off = 1; break;
      case '2': on_off = 0; break;
      case '3': on_off = 1; break;
    }
  }

  void getPS_MaxVoltage(int addr) {
    max_voltage = -1;
  }

  void getPS_MaxCurrent(int addr) {
    max_current = -1;
  }

  void getPS_OutVoltage(int addr) {
    char *r = getPS_Val(addr, "RV?");
    out_voltage = int(atof(r) * 100);
  }

  void getPS_OutCurrent(int addr) {
    char *r = getPS_Val(addr, "RI?");
    out_current = int(atof(r) * 100);
  }

  void getPS_Status0(int addr) {
    char *r = getPS_Val(addr, "STUS 0");
    status0 = (r[0] - '0') << 4;
    status0 += (r[1] - '0') & 0x0F;
  }

  void getPS_Status1(int addr) {
    char *r = getPS_Val(addr, "STUS 1");
    status1 = (r[0] - '0') << 4;
    status1 += (r[1] - '0') & 0x0F;
  }

  void getPS_Temp(int addr) {
    char *r = getPS_Val(addr, "RT?");
    temp = atoi(r);
  }

  void getPS_SetVoltage(int addr) {
    char *r = getPS_Val(addr, "SV?");
    set_voltage = int(atof(r) * 100);
  }

  void getPS_SetCurrent(int addr) {
    char *r = getPS_Val(addr, "SI?");
    set_current = int(atof(r) * 100);
  }

  void getPS_Control(int addr) {
  }

  void test_PS() {
    Serial.println("Start of test_PS");

    getPS_Manuf(ADDRESS);
    Serial.print("Manuf: ");
    if (!strlen(manuf)) strcpy(manuf, "UNKWN");
    Serial.println(manuf);
    delay(MYDELAY);

    getPS_Model(ADDRESS);
    Serial.print("Model: ");
    if (!strlen(model)) strcpy(manuf, "UNKWN");
    Serial.println(model);
    delay(MYDELAY);

    getPS_VoltageString(ADDRESS);
    Serial.print("VoltageSt: ");
    if (!strlen(voltage_string)) strcpy(manuf, "UNKWN");
    Serial.println(voltage_string);
    delay(MYDELAY);

    getPS_Revision(ADDRESS);
    Serial.print("Rev: ");
    if (!strlen(revision)) strcpy(manuf, "UNKWN");
    Serial.println(revision);
    delay(MYDELAY);

    getPS_ManufDate(ADDRESS);
    Serial.print("ManufDate: ");
    if (!strlen(manuf_date)) strcpy(manuf, "UNKWN");
    Serial.println(manuf_date);
    delay(MYDELAY);

    getPS_Serial(ADDRESS);
    Serial.print("Serial: ");
    if (!strlen(serial)) strcpy(manuf, "UNKWN");
    Serial.println(serial);
    delay(MYDELAY);

    getPS_Country(ADDRESS);
    Serial.print("Country: ");
    if (!strlen(country)) strcpy(manuf, "UNKWN");
    Serial.println(country);
    delay(MYDELAY);

    getPS_RateVoltage(ADDRESS);
    Serial.print("RateVoltage: ");
    if (rate_voltage < 0) Serial.println("UNKWN");
    else Serial.println(rate_voltage);
    delay(MYDELAY);

    getPS_RateCurrent(ADDRESS);
    Serial.print("RateCurrent: ");
    if (rate_current < 0) Serial.println("UNKWN");
    else Serial.println(rate_current);
    delay(MYDELAY);

    if (setPS_OnOff(ADDRESS, "ON")) Serial.println("Turned it on");
    else Serial.println("failed to turn it on");

    //if (setPS_Voltage(ADDRESS, 1000)) Serial.println("Set volts to 5.0");
    if (setPS_Voltage(ADDRESS, 500)) Serial.println("Set volts to 5.0");
    else Serial.println("failed to set volts");

    if (setPS_Current(ADDRESS, 0)) Serial.println("Set current to 5");
    else Serial.println("failed to set current");
  }
};

PSU test_PSU1;

void updatePumping(void) {
  // If ENC_SW high then enable blower and flashing of STATUS_LED
  if (digitalRead(ENC_SW)) {
    //Blower enable high
    digitalWrite(BLOWER_ENABLE, HIGH);
    pinMode(STATUS_LED, OUTPUT);
  } else {
    //Blower enable low and turn off STATUS_LED
    digitalWrite(BLOWER_ENABLE, LOW);
    pinMode(STATUS_LED, LOW);
  }
}  //end updatePumping

void init_LCD(void) {
  lcd.init();  // initialize the lcd
  // Print a message to the LCD.
  lcd.backlight();
}  //end init_LCD

void splashLCD(void) {
  lcd.setCursor(0, 0);  //Column, row
                        //  lcd.print("Hello, world!");
  lcd.print(PROG_NAME);
  lcd.setCursor(0, 1);
  lcd.print(VERSION);
  lcd.setCursor(0, 2);
  lcd.print("Compiled at: ");
  lcd.setCursor(0, 3);
  lcd.print(F(__DATE__ " " __TIME__));
}  //end splashLCD
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
void loop() {
  //MQTT
  client.loop();
  if (!client.connected()) {
    connect();
  }

  updateMQTTmessage();

  led0.Update();        //SSR1
  led1.Update();        //SSR2 cannot be used on systems with a stack
  led2.Update();        //SSR3 cannot be used on systems with a stack
  SENSE_24V.Update();   //Read A1 every two seconds.
  SENSE_12V.Update();   //Read A2 every two seconds.
  SENSE_AUX1.Update();  //Read A3 every two seconds.
  SENSE_AUX2.Update();  //Read A4 every two seconds.
  led3.Update();        //FAULT_LED blink
  led4.Update();        //STATUS_LED blink
  updateSHUTDOWN();     //Press switch and make blower go fast.
  UpdateEthernet();     //Check link status.
  updatePumping();      //Pumping/Standby switch,turn on blower and STATUS_LED

  //Check the AC input power by inference of the +24V.  March 2025 Redundant
  // if (!updatePowerMonitor()) {
  //    Serial.println("Bad power");
  //   ;
  // }


}  //end of loop()

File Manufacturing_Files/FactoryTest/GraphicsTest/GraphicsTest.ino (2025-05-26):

/*

  GraphicsTest.ino

  Universal 8bit Graphics Library (https://github.com/olikraus/u8g2/)

  Copyright (c) 2016, olikraus@gmail.com
  All rights reserved.

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
  THIS SOFTWARE IS PROVIDED BY THE COPYRIGHT HOLDERS AND 
  CONTRIBUTORS "AS IS" AND ANY EXPRESS OR IMPLIED WARRANTIES, 
  INCLUDING, BUT NOT LIMITED TO, THE IMPLIED WARRANTIES OF 
  MERCHANTABILITY AND FITNESS FOR A PARTICULAR PURPOSE ARE 
  DISCLAIMED. IN NO EVENT SHALL THE COPYRIGHT HOLDER OR 
  CONTRIBUTORS BE LIABLE FOR ANY DIRECT, INDIRECT, INCIDENTAL, 
  SPECIAL, EXEMPLARY, OR CONSEQUENTIAL DAMAGES (INCLUDING, BUT 
  NOT LIMITED TO, PROCUREMENT OF SUBSTITUTE GOODS OR SERVICES; 
  LOSS OF USE, DATA, OR PROFITS; OR BUSINESS INTERRUPTION) HOWEVER 
  CAUSED AND ON ANY THEORY OF LIABILITY, WHETHER IN CONTRACT, 
  STRICT LIABILITY, OR TORT (INCLUDING NEGLIGENCE OR OTHERWISE) 
  ARISING IN ANY WAY OUT OF THE USE OF THIS SOFTWARE, EVEN IF 
  ADVISED OF THE POSSIBILITY OF SUCH DAMAGE.  

*/

#include <Arduino.h>
#include <U8g2lib.h>
#include <Adafruit_NeoPixel.h>

#ifdef U8X8_HAVE_HW_SPI
#include <SPI.h>
#endif
#ifdef U8X8_HAVE_HW_I2C
#include <Wire.h>
#endif

const int NUMPIXELS = 3;
Adafruit_NeoPixel pixels(NUMPIXELS, 43, NEO_RGB + NEO_KHZ400);

/*
  U8g2lib Example Overview:
    Frame Buffer Examples: clearBuffer/sendBuffer. Fast, but may not work with all Arduino boards because of RAM consumption
    Page Buffer Examples: firstPage/nextPage. Less RAM usage, should work with all Arduino boards.
    U8x8 Text Only Example: No RAM usage, direct communication with display controller. No graphics, 8x8 Text only.
    
*/

// Please UNCOMMENT one of the contructor lines below
// U8g2 Contructor List (Frame Buffer)
// The complete list is available here: https://github.com/olikraus/u8g2/wiki/u8g2setupcpp
// Please update the pin numbers according to your setup. Use U8X8_PIN_NONE if the reset pin is not connected
//U8G2_NULL u8g2(U8G2_R0);	// null device, a 8x8 pixel display which does nothing
//U8G2_SSD1306_128X64_NONAME_F_4W_SW_SPI u8g2(U8G2_R0, /* clock=*/ 13, /* data=*/ 11, /* cs=*/ 10, /* dc=*/ 9, /* reset=*/ 8);
//U8G2_SSD1306_128X64_NONAME_F_4W_HW_SPI u8g2(U8G2_R0, /* cs=*/ 12, /* dc=*/ 4, /* reset=*/ 6);	// Arduboy (Production, Kickstarter Edition)
//U8G2_SSD1306_128X64_NONAME_F_4W_HW_SPI u8g2(U8G2_R0, /* cs=*/ 10, /* dc=*/ 9, /* reset=*/ 8);
//U8G2_SSD1306_128X64_NONAME_F_3W_SW_SPI u8g2(U8G2_R0, /* clock=*/ 13, /* data=*/ 11, /* cs=*/ 10, /* reset=*/ 8);
//U8G2_SSD1306_128X64_NONAME_F_3W_HW_SPI u8g2(U8G2_R0, /* cs=*/ 10, /* reset=*/ 8);
//U8G2_SSD1306_128X64_NONAME_F_HW_I2C u8g2(U8G2_R0, /* reset=*/ U8X8_PIN_NONE);
//U8G2_SSD1306_128X64_ALT0_F_HW_I2C u8g2(U8G2_R0, /* reset=*/ U8X8_PIN_NONE);   // same as the NONAME variant, but may solve the "every 2nd line skipped" problem
//U8G2_SSD1306_128X64_NONAME_F_SW_I2C u8g2(U8G2_R0, /* clock=*/ 13, /* data=*/ 11, /* reset=*/ 8);
//U8G2_SSD1306_128X64_NONAME_F_SW_I2C u8g2(U8G2_R0, /* clock=*/ SCL, /* data=*/ SDA, /* reset=*/ U8X8_PIN_NONE);   // All Boards without Reset of the Display
//U8G2_SSD1306_128X64_NONAME_F_SW_I2C u8g2(U8G2_R0, /* clock=*/ 16, /* data=*/ 17, /* reset=*/ U8X8_PIN_NONE);   // ESP32 Thing, pure SW emulated I2C
//U8G2_SSD1306_128X64_NONAME_F_HW_I2C u8g2(U8G2_R0, /* reset=*/ U8X8_PIN_NONE, /* clock=*/ 16, /* data=*/ 17);   // ESP32 Thing, HW I2C with pin remapping
//U8G2_SSD1306_128X64_NONAME_F_6800 u8g2(U8G2_R0, 13, 11, 2, 3, 4, 5, 6, A4, /*enable=*/ 7, /*cs=*/ 10, /*dc=*/ 9, /*reset=*/ 8);
//U8G2_SSD1306_128X64_NONAME_F_8080 u8g2(U8G2_R0, 13, 11, 2, 3, 4, 5, 6, A4, /*enable=*/ 7, /*cs=*/ 10, /*dc=*/ 9, /*reset=*/ 8);
//U8G2_SSD1306_128X64_VCOMH0_F_4W_HW_SPI u8g2(U8G2_R0, /* cs=*/ 10, /* dc=*/ 9, /* reset=*/ 8);	// same as the NONAME variant, but maximizes setContrast() range
//U8G2_SSD1306_128X64_ALT0_F_4W_HW_SPI u8g2(U8G2_R0, /* cs=*/ 10, /* dc=*/ 9, /* reset=*/ 8);	// same as the NONAME variant, but may solve the "every 2nd line skipped" problem
//U8G2_SSD1306_102X64_EA_OLEDS102_F_4W_HW_SPI u8g2(U8G2_R0, /* cs=*/ 10, /* dc=*/ 9, /* reset=*/ 8);	// same as the NONAME variant, but may solve the "every 2nd line skipped" problem
//U8G2_SSD1312_128X64_NONAME_F_4W_SW_SPI u8g2(U8G2_R0, /* clock=*/ 13, /* data=*/ 11, /* cs=*/ 10, /* dc=*/ 9, /* reset=*/ 8);
//U8G2_SSD1312_128X64_NONAME_F_SW_I2C u8g2(U8G2_R0, /* clock=*/ SCL, /* data=*/ SDA, /* reset=*/ 8);
//U8G2_SSD1312_128X64_NONAME_F_HW_I2C u8g2(U8G2_R0, /* reset=*/ 8);
//U8G2_SH1106_128X64_NONAME_F_4W_HW_SPI u8g2(U8G2_R0, /* cs=*/ 10, /* dc=*/ 9, /* reset=*/ 8);
//U8G2_SH1106_128X64_NONAME_F_HW_I2C u8g2(U8G2_R0, /* reset=*/ U8X8_PIN_NONE);
//U8G2_SH1106_128X64_VCOMH0_F_4W_HW_SPI u8g2(U8G2_R0, /* cs=*/ 10, /* dc=*/ 9, /* reset=*/ 8);		// same as the NONAME variant, but maximizes setContrast() range
//U8G2_SH1106_128X64_WINSTAR_F_4W_HW_SPI u8g2(U8G2_R0, /* cs=*/ 10, /* dc=*/ 9, /* reset=*/ 8);		// same as the NONAME variant, but uses updated SH1106 init sequence
//U8G2_SH1106_128X32_VISIONOX_F_HW_I2C u8g2(U8G2_R0, /* reset=*/ U8X8_PIN_NONE); 
//U8G2_SH1106_128X32_VISIONOX_F_4W_HW_SPI u8g2(U8G2_R0, /* cs=*/ 10, /* dc=*/ 9, /* reset=*/ 8);
//U8G2_SH1106_72X40_WISE_F_4W_HW_SPI u8g2(U8G2_R0, /* cs=*/ 10, /* dc=*/ 9, /* reset=*/ 8);
//U8G2_SH1107_64X128_F_4W_HW_SPI u8g2(U8G2_R0, /* cs=*/ 10, /* dc=*/ 9, /* reset=*/ 8);
//U8G2_SH1107_128X128_F_4W_HW_SPI u8g2(U8G2_R0, /* cs=*/ 10, /* dc=*/ 9, /* reset=*/ 8);
//U8G2_SH1107_128X128_F_HW_I2C u8g2(U8G2_R0, /* reset=*/ 8);
//U8G2_SH1107_128X80_F_HW_I2C u8g2(U8G2_R0, /* reset=*/ 8);
//U8G2_SH1107_PIMORONI_128X128_F_HW_I2C u8g2(U8G2_R0, /* reset=*/ 8);
//U8G2_SH1107_SEEED_128X128_F_SW_I2C u8g2(U8G2_R0, /* clock=*/ SCL, /* data=*/ SDA, /* reset=*/ U8X8_PIN_NONE);
//U8G2_SH1107_SEEED_128X128_F_HW_I2C u8g2(U8G2_R0, /* reset=*/ U8X8_PIN_NONE);
//U8G2_SH1107_SEEED_96X96_F_4W_HW_SPI u8g2(U8G2_R0, /* cs=*/ 10, /* dc=*/ 9, /* reset=*/ 8);#
//U8G2_SH1107_HJR_OEL1M0201_96X96_F_SW_I2C u8g2(U8G2_R0, /* clock=*/ 2, /* data=*/ 0, /* reset=*/ U8X8_PIN_NONE); 
//U8G2_SH1107_TK078F288_80X128_F_4W_HW_SPI u8g2(U8G2_R0, /* cs=*/ 15, /* dc=*/ 0, /* reset=*/ U8X8_PIN_NONE);
//U8G2_SH1108_128X160_F_4W_HW_SPI u8g2(U8G2_R0, /* cs=*/ 10, /* dc=*/ 9, /* reset=*/ 8);
//U8G2_SH1108_160X160_F_4W_HW_SPI u8g2(U8G2_R0, /* cs=*/ 10, /* dc=*/ 9, /* reset=*/ 8);
//U8G2_SH1122_256X64_F_4W_HW_SPI u8g2(U8G2_R0, /* cs=*/ 10, /* dc=*/ 9, /* reset=*/ 8);				// Enable U8G2_16BIT in u8g2.h
//U8G2_SH1122_256X64_F_4W_SW_SPI u8g2(U8G2_R0, /* clock=*/ 13, /* data=*/ 11, /* cs=*/ 10, /* dc=*/ 9, /* reset=*/ 8);        // Enable U8G2_16BIT in u8g2.h
//U8G2_SSD1306_128X32_UNIVISION_F_SW_I2C u8g2(U8G2_R0, /* clock=*/ 21, /* data=*/ 20, /* reset=*/ U8X8_PIN_NONE);   // Adafruit Feather M0 Basic Proto + FeatherWing OLED
//U8G2_SSD1306_128X32_UNIVISION_F_SW_I2C u8g2(U8G2_R0, /* clock=*/ SCL, /* data=*/ SDA, /* reset=*/ U8X8_PIN_NONE);   // Adafruit Feather ESP8266/32u4 Boards + FeatherWing OLED
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

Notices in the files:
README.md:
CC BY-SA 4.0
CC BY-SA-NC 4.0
